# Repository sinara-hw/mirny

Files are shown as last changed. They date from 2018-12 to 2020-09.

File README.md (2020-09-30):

# Mirny

Mirny is a low-cost wide-band PLL/VCO-based microwave frequency synthesiser.

## Design Files

Design files (schematics, PCB layouts, BOMs) can be found at [mirny/Releases](https://github.com/sinara-hw/mirny/releases).

## Wiki

More information can be found on the [wiki](https://github.com/sinara-hw/mirny/wiki).

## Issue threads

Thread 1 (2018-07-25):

Mirny schematics review

CannaCardo, 2018-07-25:
I sketched initial version of schematics ([link](https://github.com/sinara-hw/mirny/blob/master/PCB/Mirny.PDF)).
I've chosen [ADF4351](http://www.analog.com/media/en/technical-documentation/data-sheets/ADF4351.pdf)  ([HMC833](http://www.analog.com/media/en/technical-documentation/data-sheets/hmc833.pdf) has higher price and twice the power consumtion).
I left EEM connectors since I'm not sure which alternative (PoE/ I2C from Kasli and 12V from somewhere/ something else) would be better.
Also I've left out frequency multipliers for now. I understand that this section should be realized as separate microwave PCB and it can be designed separately. I couldn't find any off-the-shelf 40MHz-4GHz multipliers, so that would mean designing it from the beginning or perhaps using a lower bandwidth doubler/tripler?
I appreciate any suggestions and having my mistakes corrected.

gkasprow, 2018-07-25:
Do we really need CPLD here? In case of Urukul it simplified a lot, but here we have only simple SPI. LVC138 should do the job.
Common reference is also good idea. I'm pretty sure that passive divider would do the job. Check what is required power level at the REFin.
Do we need external sync input? We could simply copy clock distribution from Urukul.
If we apply divider at the VCO output, we will end up with plenty of harmonics since the output is just a square wave. Maybe we should let the user to apply the lowpass filter. It can be attached to the SMA directly. Mini-circuits offers broad selection of them.
@jordens going above a few GHz means that we have to use Rogers material which is quite expensive. We can mitigate it by using castellated RF modules dedicated to certain band. I'm a bit sceptical about  amplifier/attenuator working in 35MHz-13GHz range.

gkasprow, 2018-07-25:
Edit. It's not that bad with wideband attenuators and amplifiers.
Let's have a look at:  [HMC424ALH5](http://www.analog.com/media/en/technical-documentation/data-sheets/HMC424ALH5.pdf),  [ADRF5720](http://www.analog.com/media/en/technical-documentation/data-sheets/adrf5720.pdf), there are also plenty of amplifiers that work from almost DC to >20GHz, both from ADI and MiniCircuits. The most problematic components are baluns, but we can use asymmetrical output from the VCO chip. The VCO chip has also programmable output power but from only -4 to 5dBm, I'm not sure if this is sufficient.

gkasprow, 2018-07-25:
I think that EEM is the most capable solution since it gives the user a choice. Once the  Humpback is finished it would give the user freedom in interface selection - USB, Ethernet or DIO.

jordens, 2018-07-26:
@gkasprow
* I'd also prefer to get by without the CPLD. But there are the 4 RF switches, the attenuators, the clock mux, the output status flag from the synthesizers, the LEDs.
* We don't need the sync circuitry. Just clock.
* Right. The harmonics filters shouldn't be fixed or populated by default.
* I wouldn't bother with the ranges above 6 GHz on the basic Mirny either. Leave footprints for MMCX connectors to expose that to custom boards. Maybe we can make Miny smaller in length or width so that those boards can be next to Mirny and don't need to be mezzanines. Consequently I wouldn't bother with the ultra wideband amplifiers and attenuators. Doesn't proper matching get extremely hard if you want to do that from 30 MHz all the way up to 20 GHz?
* I'll also vote for EEM connectivity.

gkasprow, 2018-07-26:
- CPLD seem to be simpler than bunch of serial registers and gives greater flexibility. Let's leave it then.
- sure, we don't need sync.
- what about addding MMCX just about the VCO chip for one who wants to play with their own AFE. We can use VCO's second output for this purpose.
- let's expose some CPLD pins and supply for control of such AFE board. The board could sit on top of Mirny and expose its connectors via the front panel. Maybe 4HP would be enough.
- on board we install just amp, attenuator and switch for let's say 6GHz where FR4 still does the job. But the VCO can work much higher.
- you are right, playing above a few GHz is quite challenging but there are great tools to do so. Have a look at https://www.xmicrowave.com/products/

hartytp, 2018-07-30:
> I think we should survey the users and use cases to decide about:

The use-cases I can imagine for this in our group are.
1. Driving microwave EOMs up to 3.2GHz (calcium hyperfine splitting). This requires a tuneable, but not frequency agile, microwave source with amplitude control and (real-time) switching.
2. Providing a fixed-frequency LO for upconversion. Similar requirements to above

So, my answers to @jordens questions would be:
  - Since we'd want some way of controlling the RF switches from Kasli in real time, EEM seems the right solution for us, but LVDS-over-RJ45 + external power (PoE?) could also work. We could live with ethernet only, and add an external switch, but that's less convenient. I hate USB for lab stuff
  - My preference for the reference would be 125MHz from Kasli via an internal MMCX cable like Urukul. We could probably get away with an XO, but it's nice to have it referenced to our atomic reference so that one doesn't need to check the frequency ever. Since we will generally use this in a rack with Kasli, it seems silly not to use the reference outputs that Kasli provides
  - Power: either EEM or PoE, depending on what we decide above seems easiest
  - We don't need much in the way of fancy features

jordens, 2018-08-01:
* Let's do EEM (will need to be dual slot again for high resolution RF switch signals) and push the rest (Ethernet, PoE, etc down to Humpback/Kasli)
* You'll be checking the frequency anyway due to the finite resolution of the PLL, even with a perfect reference the output won't be what you request in many cases.
* I'd like to leave the XO on board for Humpback use cases or where the MMCX cabling is unnecessary and annoying. And I'd like to make the XO the default. I think it would be best if on one input of the mux there is the SMA and the MMCX in parallel with a capacitor population choice (or even just hve them in parallel, the stub is probably small enough to not matter). And on the other input the XO. That covers all use cases that were mentioned.
* Maybe we can find a less power hungry and cheaper fanout (we don't need the 8 outputs or the divider features).
* Yes. Expose the high frequency (multiplied) output of the VCO on MMCX (DNP FWIW) for custom AFE purposes. Keep the base board good to 4 or 6 GHz.

hartytp, 2018-08-01:
> Let's do EEM (will need to be dual slot again for high resolution RF switch signals) and push the rest (Ethernet, PoE, etc down to Humpback/Kasli)

:+1:

I could definitely live without the high resolution switching/second EEM for this design. But, given that we have the CPLD, if we're going to have one EEM connector, the overhead in adding a second is so low that there doesn't seem any point not having it.

hartytp, 2018-08-01:
> We might want to put a bit more power into the preamplifiers (20dBm output instead of 10dBm) since Mirny is not ad hungry as Urukul.
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
jordens, 2019-01-03:
* Check the output bias inductors. https://freenode.irclog.whitequark.org/m-labs/2019-01-03#1546514242-1546514169; Optimize for wideband match.

hartytp, 2019-01-12:
Why did you decide to go for the adf4355 in the end rather than the adf4356?

hartytp, 2019-01-13:
@CannaCardo some relatively minor comments:
- [ ] it's convention to have traces to ground going down. e.g. having looked at a lot of schematics, I find it mildly jarring that the output capacitors around IC16 go upwards from the trace (same for the LED)
- [ ] in the power budget, can you add a column heading to make it clear which numbers are mA and which are mW etc
- [ ] before going to manufacture we need to finish debugging the power supply issues on urukul related to the LT1763
- is it really necessary to have 4 separate mezzanines rather than just having a single 4-channel mezzanine? IME having lots of narrow mezzanines is mechanically worse and makes layouts nasty on the mezzanines (lots of dead space around boards, can't share common components between boards). What do you think about our idea for stabilizer of having the mezzanine have its own FP and using pin header for the board-board connections (as well as the SMPs)?
- why are there NC pins on the mezzanine connector? Better to ground them?
- [ ] can we reserve some pins on the FPGA for HW rev?
- [ ] PN for TR1? What frequency range does it cover?
- [ ] worth picking a filter that goes up to the 6.8GHz fundamental VCO range? (or at least to the max BW for other components like switches etc)
- [ ] looking at the eval board schematic for the ADF5356, I can see a few differences. e.g. capacitance vales (places where they've used, say, a 10uF and you've used 0.1uF for decoupling). Also, some power pins they've run from separate LDOs, where you've run them from the same LDO. Please double check the eval schematic and make sure that all differences are for a good reason

sbourdeauducq, 2019-01-13:
Probably too late for this design, but in the future let's try to use Lattice FPGAs instead of Xilinx CPLDs (AFAICT they would do the job there), so we can get rid of ISE/Vivado.

jordens, 2019-01-15:
Stick with the CPLD.
IME the free tools for this job are not ready yet. There are still lots of problems and they don't make me nearly as productive as ISE for CPLDs. Also from what I have seen, at least for this application, the CPLD is faster and has more reproducible delays than the ice40.
Vivado won't go. We will be needing Vivado for the foreseeable future.
I'd rather spend my time fixing design flaws and improving the project than trying to get rid of something that we definitely won't get rid anytime soon.

hartytp, 2019-01-15:
One other question: do we really want to bother with all the complexity/mechanical issues around RF mezzanines for this project? Can we get away with something like using solder jumpers to swap between two paths: RFA + AFE; and RFB directly at the output?

If we do need AFE mezzanines, another option that might be simpler/better would be to use a similar form-factor to Stabilizer AFEs (separate EEM FP, pin-header for board-board connectors) and use short coax leads to internally route the microwave output from Mirny to the AFE. This could be simpler and more robust than trying to make the stackup work with SMP bullets.

jordens, 2019-01-15:
I agree. That's what I argued for in https://github.com/sinara-hw/mirny/issues/1#issuecomment-445353727 And a single or at most two mezzanines is fine IMO.
But I would not try to capacitor-route RFoutB to the front panel. Just MCX/MMCX and a pigtail to the panel would probably be electrically better and simpler. For the AFE I also don't like squeezing it into the 4HP space and I don't like the constraint mechanics and interference due to panel/rf/digital connectors.

hartytp, 2019-01-15:
Thakns @jordens. So in order of preference it would be (a) scrap the AFE and use a coax pig-tail (connectors chosen to choose the frequency range) to route RFB somewhere accessible (b) if we have to keep the AFEs then let's limit it to just 1 AFE.

For the pig-tail approach, I assume you'd route them to an adjacent 4HP FP that, for example, just has 4 feedthrough SMAs mounted?

CannaCardo, 2019-01-15:
> can we reserve some pins on the FPGA for HW rev?

I've added 2, should be more than enough.

> PN for TR1? What frequency range does it cover?

TCM2-43X+,  it covers 10MHz-4GHz. Added PN on schematic.

> worth picking a filter that goes up to the 6.8GHz fundamental VCO range? (or at least to the max BW for other components like switches etc)

LFCN-3800+/ LFCN-4400+ would cover BW of front end components (everything works up to 4GHz).

>
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

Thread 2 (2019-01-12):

power supply bug

gkasprow, 2019-01-12:
@jordens discovered [issue](https://github.com/sinara-hw/Urukul/issues/20) with the power supply in Urukul
The DC/DC converter has an output voltage higher than the specification says. We should look for another buck converter producing 7.5V
Another issue is bypass capacitor of LDO - with 100nF it oscillates.

gkasprow, 2019-01-28:
@CannaCardo
- [ ] C170, C175 must be 100pF. Replace with the component from libraries, do not edit parameters with value.

CannaCardo, 2019-01-29:
fixed

hartytp, 2020-07-13:
@CannaCardo should we close? Which release is this fixed in?

CannaCardo, 2020-07-14:
It was fixed in v1.0rc4.

gkasprow, 2020-07-16:
@CannaCardo are you currently working on new revision or only are closing old issues?

CannaCardo, 2020-07-16:
Just closing, I'm working on the TDC atm.

Closed 2020-07-14.

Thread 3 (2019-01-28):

a few last minor issues

gkasprow, 2019-01-28:
- [ ] Please do not add DNP as the Mounted parameter because it is not transferred to the production files. Use variant instead and mark it as not mounted.
- [ ] remember to generate the production files with the appropriate variant enabled
- [ ] move JTAG connector above the ARTIQ logo. The existing location will be covered by the CPCIS adapter.
- [ ] add nice copper balancing as I did for the Banker. You will need this [file](https://www.dropbox.com/s/omaalewtysv5mm3/copper_balancing2.PcbDoc?dl=0). This is a simple hack. Lock all objects on Keep out layer. Then copy keep out mesh with polygons from the file I specified. The polygon parameters are critical. Regenerate polygons. Select the keep out layer only. Remove un-locked mesh from your design. In Xpedition, such copper balancing option costs 10k $ :D My hack is for free.

CannaCardo, 2019-01-29:
- All components marked as DNP are also marked as such in variants.
- There's a separate pick & place, bom and schematic file for every variant, gerbers and drill files are the same across all variants
- JTAG connector moved
- I've added balancing pours with a polygon cutout near rf sections, as floating copper there could cause some troubles later.

hartytp, 2020-07-13:
@CannaCardo this issue looks complete. Can we close?

Closed 2020-07-14.

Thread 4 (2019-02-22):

tag v1.0 production

jordens, 2019-02-22:

jordens, 2019-08-28:
@gkasprow @CannaCardo could you tag the v1.0 production commit and add the correct PDFs/BOM/gerbers?

gkasprow, 2019-08-28:
done

jordens, 2019-08-29:
thanks

Closed 2019-08-28.

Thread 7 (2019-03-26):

Mirny v1.0 tests

gkasprow, 2019-03-26:
The Mirny is ready for tests
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

gkasprow, 2019-03-26:
- [ ] 0R installed instead of  C68 ABCD causing short of 5V power supply rail. 3V3 rail depends on this voltage. After removing shorts, all supples are fine.

gkasprow, 2019-03-26:
CPLD is detected over JTAG

gkasprow, 2019-03-26:
@CannaCardo it's time to connect ADI devkit and check if the synthesizers are working

CannaCardo, 2019-03-26:
Ack, I should be in Warsaw on Thursday to test it.

jordens, 2019-03-26:
Nice!

gkasprow, 2019-04-04:
the CPLD cannot really set Hi-Z on CLK_SEL signal. the state is close to VCC.
With a touch of the probe, the Hi-Z appears and stays until power down. So it looks like additional init sequence would be needed that first sets low state and then Hi-Z.

gkasprow, 2019-04-04:
Other than that Mirny works with ADI devkit as a controller.

gkasprow, 2019-04-04:
We have some issue with 26kHz and its second and third harmonics. The carrier is 100MHz. Moreover, the analyzer sees the carrier shifted by 1kHz.
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

gkasprow, 2019-04-04:
It looks like the noise source was outside. With analyzer and supply connected to same mains outlet the spectrum looks much better now.
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

jordens, 2019-04-04:
It works on urukul. Just tristate it.

jordens, 2019-04-04:
What are the conditions and settings there? With div32 and a 3.4 GHz vco the datasheet gets to -131dbc/hz at 10khz and 64 mhz pfd.

gkasprow, 2019-04-04:
the SSA I have is not a really good one. It is a software option to the spectrum analyzer. It's good for quick debugging, not real measurements.
With CMC added to the 12V power entry, the 26kHz peak disappeared.
We will make measurements with real SSA in a few days.

gkasprow, 2019-09-18:
[Here](https://www.dropbox.com/s/8773l9b8eklw5bs/praca%20mgr%20277384_inz.pdf?dl=0) is the thesis of Krzysztof Belewicz

jordens, 2019-09-18:
Well done. Congrats @CannaCardo

jbqubit, 2019-09-18:
Thanks for the detailed writeup @CannaCardo! Great work!

Closed 2020-09-30.

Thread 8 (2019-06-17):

replace Si53312-B-GM by Si53340-B-GM

jordens, 2019-06-17:
* No need for 6 unused outputs
* No need for input divider
* No need for power-hungry LVPECL
* Removes one BOM line

gkasprow, 2020-09-30:
done
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

Closed 2020-09-30.

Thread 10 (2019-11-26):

[RFC] Phase lock application

hartytp, 2019-11-26:
We have an application where we'd like to generate two tones at 1.6GHz. One needs to be locked to a fixed external reference, the other needs to be phase locked.

It seems like Mirny might offer a nice way of doing this if we did something like:
- Add a footprint for a low phase noise VCXO which can be populated instead of the XO (or, better, aim for a pin-compatible part)
- Hook the tuning pin to an MMCX/whatever. Maybe add an RC filter or even a diff-amp to give noise rejection. All of this would be DNP by default
- have some means of getting some channels clocked from the VXCO and some from the external reference. This could be as simple as adding a DNP'd MMCX connector for each channel and solder jumpers that can be used to inject an external clock (that's somewhat useful for debugging anyway).

Thoughts?

jordens, 2019-11-26:
To clarify: you want one voltage controlled Mirny channel and one controlled via a reference frequency?
Adding the tuning option to the XO is good.
And solder jumpers to select between DNP MMCX per channel and the clock fanout is also fine. But simpler yet and without any new connectors, you can use jumpers to choose between IC17:Q1-Q3 (VCXO or MMCX) and IC13:Q1-Q3 (#8, FP SMA or VCXO/MMCX) for three of the four channels. That way you can run 0 to 3 channels from the VCXO (or MMCX) and 4 to 1 channels from the SMA input.

hartytp, 2019-11-26:
> To clarify: you want one voltage controlled Mirny channel and one controlled via a reference frequency?

Yes. Basically, one as a reference for the mixer LO and one that we can lock.

We'll probably end up using Stabilizer for the lock so this could potentially be a Stabilizer mezzanine but the work to reward effort feels better by reporuposing Mirny.

> But simpler yet and without any new connectors, you can use jumpers to choose between IC17:Q1-Q3 (VCXO or MMCX) and IC13:Q1-Q3 (#8, FP SMA or VCXO/MMCX) for three of the four channels. That way you can run 0 to 3 channels from the VCXO (or MMCX) and 4 to 1 channels from the SMA input.

Yep, that's another route I thought of which I'd also be happy with.

hartytp, 2019-11-29:
Having said all that, this would be pretty trivial to do as a Stabilizer AFE card. 1 Crystal, 2 PLLs and some regulators and that's it AFAICT. Basically just a copy-paste from a few other designs so <1 day of work I'd guess.

gkasprow, 2019-11-29:
You can also connect Mirny to the stabilizer via EEM.

dhslichter, 2019-12-02:
Why not use Mirny as a carrier generator at ~1.25 GHz, split the output, and then use two separate mixers with two Urukul channels to mix up to 1.6 GHz?  The carrier and other sideband can be stripped easily with high-pass filters/notches, then all frequency and phase tuning between channels can be done digitally with the Urukuls.  If the Mirny can be locked to an external reference already, you're set.  You could make a little eurocard with splitter, mixers, filters, some SMA connectors on the front panel, even some ERA-4 or equivalent amps to boost the output power a bit if desired (without amps it could be a completely passive board, with amps you would have to provide a power supply from in the crate).

hartytp, 2019-12-02:
> Why not use Mirny as a carrier generator at ~1.25 GHz, split the output, and then use two separate mixers with two Urukul channels to mix up to 1.6 GHz?

(a) because there is a doubling cavity involved so we'd need 1.6GHz and a 3.2GHz tones (b) because it feels more expensive/complicated than hooking a stabilizer up to Mirny. What would do the digital modulation of Urukul? Kasli? I'd like this to be a standalone unit with good ethernet diagnostics (e.g. streaming noise traces). That feels easier to do with Stabilizer than Kasli.

I think the Vco tune input is a good thing to have for Mirny. But, currently I'm leaning towards doing this as a high-frequency version of Pounder with the DDSs replaced by ADF PLLs.

hartytp, 2019-12-31:
closing in favour of https://github.com/sinara-hw/Homodyner/issues/1 and https://github.com/sinara-hw/mirny/issues/11

Closed 2019-12-31.

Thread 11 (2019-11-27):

VCXO

hartytp, 2019-11-27:
The current XO is a crystek [CCHD-950](https://www.crystek.com/crystal/spec-sheets/clock/CCHD-950.pdf) costing ~£20 in singles

The a footprint-compatible VCXO part is [CVHD-950](https://www.crystek.com/crystal/spec-sheets/vcxo/CVHD-950.pdf). This is about the same cost (actually, very slightly cheaper) and has decent [availability](https://octopart.com/search?q=cvhd-950-100.000).

I'm happy to keep the XO as the default population option, but can we have either a variant with the VCXO or just an annotation mentioning that this is a suitable alternative part?

I'd like to break the tuning pin out to an MMCX. Probably via a difference amplifier (to remove ground small levels of common-mode noise), offset addition and attenuation to match +-10V to the VCXO's range. Then probably an RC filter to kill any high-frequency noise. I'll sketch out a suggestion for this design at some point when I have time.

hartytp, 2019-11-27:
@cjbe FYI this is the VCO noise spec https://octopart.com/search?q=cvhd-950-100.000

jordens, 2019-11-27:
I think we already went for the tunable part in Urukul and mid-pointed tuning input.

hartytp, 2019-11-27:
For reference, the PLL noise model is:
- assume f_ref=125MHz, N = 13 (f_out=1.625GHz)
- in-band phase noise floor is `-227dBc/Hz +10log10(125e6) + 20log10(13)=-124dBc/Hz`
- FWIW, that's equivalent to reference noise of -146dBc/Hz
- 1/f noise is `-121dBc/Hz + 10log10(10kHz/f_offset) + 20log10(f_rf/1GHz)` so the 1/f phase noise at 10kHz offset is `-117dBc/Hz`

VCO noise is

![Uploading image.png…]()

hartytp, 2019-11-27:
If that's actually an issue and we ever made a mezzanine, we could consider using e.g. an HMC830 which has ~10dB lower noise, but I don't really think it's a problem. tl;dr it looks like this will work nicely!

hartytp, 2019-11-29:
FWIW, the HMC830 specs are

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

So 3dB better for the in-band noise floor (although, note that the PFD can only hit 125MHz for integer-N mode)

I believe the flicker noise floor is normalized to 1Hz offset, so equivalent to 228 at 10kHz. i.e. approx 7dB better than the ADF PLL. So, not a huge difference between the two TBH.

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

The ADF VCO noise actually looks a little better.

So tl;dr either part is probably fine.

gkasprow, 2020-09-30:
I copied the schematic from Urukul
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

Closed 2020-09-30.

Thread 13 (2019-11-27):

transformer part numbers missing from schematic

hartytp, 2019-11-27:
Also, let's make sure these are done consistently with other designs like phaser.
- where possible/appropriate use same transformer part numbers as other designs
- for external clock inputs try to do the layout such that we can use the transformer to provide galvanic isolation (not an option for microwave inputs)

gkasprow, 2020-09-30:
what about the same transformers as in Phaser design?
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

hartytp, 2020-09-30:
fine by me

hartytp, 2020-09-30:
@gkasprow shouldn't the input ground be tied to the SMA ground, and only connected to the PCB ground through the 0R resistor though? That way we can use the transformers to provide galvanic isolation if desired (but let's not make that the default population option). IIRC that's what we're now typically doing elsewhere...

gkasprow, 2020-09-30:
ah, yes, good point.

Closed 2020-09-30.

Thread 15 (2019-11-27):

PGOOD too high

hartytp, 2019-11-27:
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

In practice it may not matter as the pull up is weak, but ideally we should avoid clipping on the ESD diodes

hartytp, 2019-11-27:
1.5V/5.6K is 300uA so within spec, so maybe not worth changing the design?

hartytp, 2019-11-27:
I guess this is consistent with the latest Urukul, so we decided it's not actually an issue

hartytp, 2019-11-27:
Worst-case current is 7.5V/5.6K = 1.33mA so a bit on the high side but still within the abs max ratings.

Closed 2019-11-27.

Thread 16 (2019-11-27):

TPS62175DQC

hartytp, 2019-11-27:
Why arent' we using the same PN as Urukul out of curiosity? Makes the design review easier if I'm just looking for diffs between the two designs...

gkasprow, 2020-09-30:
it is already used in DIO boards. We can switch to the same one as in Urukul.
In Urukul it was used to generate 7V5 which was out of it spec that's why was replaced by TPS62148.
Here we generate 5V5 which is fine.

hartytp, 2020-09-30:
@gkasprow I don't feel strongly about this (beyond a general preference for reusing components from other design where possible) so do what you think is best.

gkasprow, 2020-09-30:
Let's go for Urukul one. It has higher current, mezzanines may need it.

Closed 2020-09-30.

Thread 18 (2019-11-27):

Different supply for digital rails?

hartytp, 2019-11-27:
Shouldn't the noisy PLL digital rails be run from a separate supply to the analog rails? E.g. run them directly from their own SMPSs.

hartytp, 2019-11-27:
Maybe not needed if the digital interface is only used during configuration?

gkasprow, 2020-09-30:
I'm a bit afraid of connecting it to the "digital" P3V3. I can replace the FB with an inductor that makes a low frequency filter.

gkasprow, 2020-09-30:
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

hartytp, 2020-09-30:
sure, whatever you think is best here...

Closed 2020-09-30.

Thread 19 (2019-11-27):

Analog supply decoupling

hartytp, 2019-11-27:
Should there be FBs to isolate the various anlaog supplies that are derived from the same LDO?

hartytp, 2019-11-27:
Well, we're actually not far off the [eval board design](https://www.analog.com/media/en/technical-documentation/user-guides/EV-ADF5356SD1Z-UG-1087.pdf).

The only real difference I see is that the eval board uses separate LDOs for the output stages. I assume this isn't really worth doing and the FBs will be fine...

Other than that I didn't spot any issues during a quick design review. Nice job all who worked on this one!

gkasprow, 2020-09-30:
can we close it?

hartytp, 2020-09-30:
@gkasprow so long as you're happy with the current design (e.g. not using separate LDOs as the eval board does) you can close this issue. I'll leave the final call to you.

Closed 2020-09-30.

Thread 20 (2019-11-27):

RFoutB-

hartytp, 2019-11-27:
why isn't this labelled AGNDrf2 and tied directly to GND1 as in the eval board?

jordens, 2019-11-28:
I think this depends on the chip. The non-doubling are differential. Otherwise this is the Rf b return.

hartytp, 2019-11-28:
That's what I assumed. AFAICT for the chip on Mirny right now this should be grounded as in the eval board. Maybe add shunt resistor to ground in parallel and DNP the cap?

jordens, 2019-11-28:
I'd just test whether this works fine with the doubling variants and if not check whether making the R 0 is sufficient to enable AC return. If it works fine as now then no changes are needed.

gkasprow, 2020-09-30:
I added 0R for ADF5356/5355 versions.

Closed 2020-09-30.

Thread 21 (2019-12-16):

[RFC] OPLL AFE

airwoodix, 2019-12-16:
We are considering using Mirny to generate the ca. 7 GHz MW we use to mix down rubidium Raman phase lock beatnotes (ca. 6.8 GHz). Besides the necessary range extension (using RFoutB), it would be great to integrate most of the chain as a Mirny addon-board.

The full chain would be something like (x4):

```
PD input -- gain +16dB  -- DBM -- LPF (200 M) -- [PFD -- CP] -- LPF -- output
                            |
                     7 GHz from RFoutB
 ```

For the PFD/CP, something cheap and simple like ADF4154 or even ADF4110 would be great. The reference for the the PFD would come from an external Urukul channel. Since there're four lines free on the Mirny EEM, these can be routed to the AFE and control the PLL chip.

RFoutB probably needs preconditioning to saturate the mixer.

A simpler version of the board would drop the PLL if that's too complicated / not generic enough. In any case, a down-converted beatnote monitor is a useful feature.

What are your thoughts?

jordens, 2019-12-16:
A heterodyne design might be best. You would be able to reuse Pounder. 1st IF at ~100 MHz.

```
Mirny - gain - DBM LO
PD - gain - DBM RF - LPF - Pounder (gain, DDS LO, DBM, LPF, gain) - Stabilizer
```

hartytp, 2019-12-16:
@airwoodix Hi! BTW this is well-aligned with something we're thinking about.

We had a couple of thoughts about ways of doing this. e.g. https://github.com/sinara-hw/mirny/issues/10

As @jordens points out there are many ways of skinning a cat, but reusing Pounder seems like a good idea.

Currently, the option I'm leaning towards for our application would be to create a high-frequency (1-4GHz at least) version of Pounder. The idea is
- have the entire RF chain (filters, mixer, amps, variable attenuator etc) on a Stabilizer mezzanine.
- replace the twin DDS on pounder with a pair of PLLs.
- one PLL uses an external reference
- the other uses a ~100MHz VCXO that's steered by the DAC on pounder to provide the phase lock

This provides a really nice integrated solution to the problem that can span a wide frequency range (can also have RF and LO at different frequencies if e.g. modulation is done before optical doubling). We can largely reuse the pounder design so the HW changes are relatively minimal.

jordens, 2019-12-16:
The other thing that I would consider in general for these phase measurements is going superhet and having some ~200 kHz IF (instead of DC) on Pounder and doing the rest in digital domain in Stabilizer. That's a free rejection of all the low frequency noise and instability near DC. Just needs proper clocking of Stabilizer.

hartytp, 2019-12-16:
@airwoodix what PFD/CP are you thinking of? Are you intending to lock the ADF to the beat note directly? Might be better to lock the ADF to a VCXO with a high bandwidth and then lock the VCXO to stabilize the beat note. The VCXO has much lower noise/better stability than the ADF VCO so you can use a narrower bandwidth lock, can do S/H etc

hartytp, 2019-12-16:
That's what we would do on our high-frequency Pounder version...

airwoodix, 2019-12-16:
Thanks for the feedback. Great ideas, I was looking at something much simpler (and cheaper).

From a pure accounting point of view, I'd priviledge a Mirny mezzanine since this is one board less (we need RFoutB gain anyway so the Mirny board is unavoidable).

@hartytp I was looking at ADF4154 as PFD/CP with no extra VCO but it sounds indeed convincing to add an extra VCXO. The main argument was to keep the system as simple as possible and the availability of lines on the EEM Mirny is attractive to me.

The phase lock's frequency offset needs to be dynamically controlled. The easiest would be over EEM, otherwise we'd need a lot of extra fw development for Stabilizer. Hooking up a Urukul channel or multiplexing a DDS next to the PLL chip on the Mirny addon board is easy and integrates seamlessly into the system (saving the indirection through Stabilizer).

@jordens of course, a superheterodyne approach is better but also more complex.

hartytp, 2019-12-16:
> Thanks for the feedback. Great ideas, I was looking at something much simpler (and cheaper).
From a pure accounting point of view, I'd priviledge a Mirny mezzanine since this is one board less (we need RFoutB gain anyway so the Mirny board is unavoidable).

FWIW my proposal is also only 1 board (stabilizer) + 1 AFE card so I don't think it will be more expensive than Mirny + AFE in terms of hardware production costs.

What are you planning to use to do the feedback controller? Will you do this in analog (boo!) or have a digital controller. I'd suggest you consider the latter. Not just because it's so much nicer to tune loop filters digitally (particularly if you might at some point want e.g. a double integrator to kill acoustic noise without having to have a really wide lock bandwidth etc), but because of the diagnostics. e.g. we've found it so useful to be able to stream error signals for diagnostics (see if a lock is ringing) do digital relock etc.

From that point of view using Stabilizer is the obvious choice for the lock (whether you use Stabilizer to drive the VCXO on Mirny or put the PLL on a Stabilizer AFE).

> @hartytp I was looking at ADF4154 as PFD/CP with no extra VCO but it sounds indeed convincing to add an extra VCXO.

I can't remember (don't have schematics in front of me) if Mirny even exposes the Vtune input right now to allow an external lock signal. So, locking like that might require hardware modifications.

> The main argument was to keep the system as simple as possible and the availability of lines on the EEM Mirny is attractive to me.

Stabilizer is an EEM too :)

Anyway, I take all your points. As I said, there are many ways of skinning a cat. I have my own ideas about how I'd do this but I'll be really interested to see what system you settle on. If you do a nice job of it then it would be a really welcome addition to the Sinara ecosystem.

airwoodix, 2019-12-16:
> FWIW my proposal is also only 1 board (stabilizer) + 1 AFE card so I don't think it will be more expensive than Mirny + AFE in terms of hardware production costs.
Given the frequency range, we need to use the ADF5356's second output (``RFoutB``). Would you expose it directly on the front panel from the SMP connectors? I'd take the opportunity to at least at gain (possibly with digital step attenuators driven by a SR like the PGIAs on Sampler).

We'd mostly use Stabilizers for the feedback (I totally support your points), but also likely Toptica DLC for the diode lasers (because we anyway use them for the current/PZT drivers). Hence the idea to put most of it on Mirny... Other experiments in the group might also be more convinced if they only need a Humpback and a Mirny + AFE (ok, with a lot of software, this is also valid for Stabilizer (as EEM upstream) + AFE + Mirny).

> I can't remember (don't have schematics in front of me) if Mirny even exposes the Vtune input right now to allow an external lock signal. So, locking like that might require hardware modifications.

It doesn't. Either we misunderstood ourselves or I'm stupid but I don't see the need to feedback on Mirny. I had an optical PLL "à la" Vescent D2-135 in mind so we'd feed back on the laser directly. Or is there something wrong with this approach?

>> The main argument was to keep the system as simple as possible and the availability of lines on the EEM Mirny is attractive to me.

> Stabilizer is an EEM too :)

Sorry should have written "on Mirny's EEM". With @jordens Mirny CPLD gateware, EEM4-7 are free to use on the mezzanine.

I'll work out the options tomorrow and come back with more questions :) Overall, I'd mostly be happy minimizing the amount of firmware/gateware to write. And honestly, as far as I'm concerned, it's easier to write glue gateware for the Mirny CPLD and a simple coredevice driver than extending the Stabilizer firmware.

hartytp, 2019-12-16:
> I had an optical PLL "à la" Vescent D2-135 in mind so we'd feed back on the laser directly. Or is there something wrong with this approach?

Aah, okay, makes sense.

I assumed you were using one output of Mirny to drive a modulator and wanted to do the optical phase lock by feeding back to the RF.

gkasprow, 2019-12-30:
Can we move it to the [new repo](https://github.com/sinara-hw/Pounder_HF) ?

hartytp, 2019-12-30:
@airwoodix can you sketch out a full block diagram of the system you want to build please?

 I have in mind a stabiliser homodyne afe based on pounder. Idea is to use one pll to provide a mixer ref. Lock is achieved either (eg population options) by using an external modulator which is driven by a second pll who’s ref is provided by a vcxo driven by stabiliser or using the stabiliser output to drive some other actuator (eg laser PST).

If there is enough overlap it would be good to design an afe that can cover both cases.

airwoodix, 2020-01-02:
I'd lean towards separating the frequency ranges (6G+ vs 3G-) and build two daughter boards: one for Mirny that deals with applications that require RFoutB and one like Pounder/Homodyner for the work in the 3G- domain.

For the 6G+ range, what about a Mirny AFE with chains like this:

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

The application is our typical phase lock for the Rb interferometry systems. The RF input is a beatnote at ca. 6.8 GHz. RFoutB covers the range 6.8 GHz - 13.6 GHz. Components suggestions try to cover at least up to the (neutral) Cs hyperfine frequency at 9.2 GHz.

RFoutB delivers 0-2 dBm, with -20 dBm fundamental VCO feedthough. The HPF doesn't cost much and probably makes this better. The mixer needs 17 dBm LO drive. All amplifiers have the same footprint. Would be great to keep the output LPF in a MCL FV1206 package to have more flexibility (and stay compatible with Urukul).

To achieve phase/frequency offset lock, the RF signal can be fed to Pounder as @jordens suggested. I think that my initial suggestion to put the phase detector on the Mirny AFE is not flexible enough although the full solution will require a significant amount of firmware development for Stabilizer.
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
hartytp, 2020-01-02:
> It's an option, but less convenient -- I'd rather just have Stabilizer and a single AFE than: Stabilizer+Pounder+Mirny+AFE as well as the wiring between them and something to drive Mirny (Kasli? Humpback? Stabilizer EEM connector and write Stabilizer firmware to control Mirny?).

A bit of extra context: we're looking for a fixed frequency offset lock between a pair of lasers. So, it's useful to have something that can easily run standalone (rather than plugging into one of our ARTIQ Kaslis). Hence a PoE module like Stabilizer is ideal for this (although you could still connect it to a Kasli, albeit with limited timing resolution, using the Stabilizer EEM).

gkasprow, 2020-09-30:
@hartytp what are your needs here? Shall we proceed? The Almazny is nearly done and we can take care of this design.

gkasprow, 2020-09-30:
@airwoodix

hartytp, 2020-09-30:
@gkasprow for our specific application, the best method would still probably be a specific Stabilizer mezzanine. As described above, this would be something like:
- Two PLL ICs
- One clocked from an external reference, used to feed mixer LO
- the other clocked from a VCXO that is tuned by the stabilizer DAC to lock
- RF input/mixer/signal conditioning largely copied from Pounder, but changing the bandwidth of some components to work to a few GHz

The current Mirny design gives us a way of building something like the above using a stabilizer + mirny + containerized mini circuits bits. Modulo concerns about the cross-talk from the clock jumpers and CMRR of the VCXO input, I think this does everything we could want without building a dedicated card (which may be more effort than it's worth).

airwoodix, 2020-09-30:
@gkasprow are the schematics of the Almazny already online?

gkasprow, 2020-09-30:
@shanasz has issues with github, they should arrive today.

Closed 2020-09-30.

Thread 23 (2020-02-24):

More flexible clock routing

hartytp, 2020-02-24:
https://github.com/sinara-hw/mirny/issues/10#issuecomment-558618102

gkasprow, 2020-09-30:
@hartytp @jordens would such wiring work for you?
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

hartytp, 2020-09-30:
That arrangement allows one to select between the SMA and the VCXO/MMCX on a per-channel basis. For our use-cases, it would be more convenient to select between the MMCX and the SMA/VCXO on a per-channel basis, but the above is acceptable. @jordens preferences here?

@gkasprow based on our previous experience, I guess we expect quite a bit of cross-talk from the DNPd jumpers, do we?

gkasprow, 2020-09-30:
we can use T-type jumpers, when unused, the central part is grounded.

jordens, 2020-09-30:
Either is fine by me.

jordens, 2020-09-30:
Default population being all channels clocked from IC13.

gkasprow, 2020-09-30:
I added such a scheme. To avoid dangling nets, the segment is terminated on both sides. To improve isolation, unused net segments can be grounded. That should solve the issue with crosstalk.
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

gkasprow, 2020-09-30:
I also changed the assignment - now we select between MMCX and the SMA/VCXO.

gkasprow, 2020-09-30:
The layout/routing of the clocking section
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

Closed 2020-09-30.

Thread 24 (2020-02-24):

VCO tune CMRR

hartytp, 2020-02-24:
https://github.com/sinara-hw/Urukul/issues/37#issuecomment-588092910

To do: try driving the VCO from a stabilizer and measure the DDS output noise spectrum. If it's bad, look at putting in a proper InAmp solution with much better CMRR (and maybe a CM/DM EMI filter).

gkasprow, 2020-09-30:
I took the Urukul [issue](https://github.com/sinara-hw/Urukul/issues/37) into account
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

hartytp, 2020-09-30:
This would be clearer with the population options shown, but I think I understand what's going on...I'd feel more confident with this if we'd tested on Urukul, but the approach seems sensible (assuming we can get away without a true differential front end to suppress ground noise)

hartytp, 2020-09-30:
@gkasprow what limits the tuning bandwidth here? Is it C100? I assume we want a filter to stop RF pickup etc getting onto the VCO.

gkasprow, 2020-09-30:
default population:
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
the issue is with filtering the + divider - for low frequency if will have more than 5k and its CMRR for low frequency would be worse. I'd prefer to stay with one used in Urukul.

hartytp, 2020-09-30:
don't C100 + R78 give an nice filter?

gkasprow, 2020-09-30:
it does. But in one of the Urukul issues somebody wanted additional RC filter at the opamp positive input. That's why I added R99, R100 and C107

hartytp, 2020-09-30:
Fine. Well, we have a pretty sensible topology and lots of pads to play with here, so it seems like a decent starting point. Would be good for someone to actually play with a phase lock...

Closed 2020-09-30.

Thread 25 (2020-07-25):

High frequency mezzanine

cjbe, 2020-07-25:
How far advanced are the plans for the high frequency mezzanine?

I need some sources around 5-12 GHz for which Mirny+mezzanine would be ideal. For my use case all I would require on the mezzanine is matching and switching. Switchable attenuation would be a nice to have.

Does anyone have any appetite to specify / use / build this? If so I can put some effort into crystallising specifications.

gkasprow, 2020-07-25:
@cjbe So far there was no such request.
If you specify it, we will build it. I have a budget for RF engineers and prototypes.
Just find suitable RF components and write the spec.

gkasprow, 2020-07-25:
U can use a free RF QUCS simulator to do a rough estimation if the components make sense.
This is an example project of ISM transverter I designed and my colleague verified with this tool
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

cjbe, 2020-08-01:
Here is a broad specification:
* max output power: ~5-10 dBm (enough to match well to standard 25-35 dB gain amps)
* frequency range: 4 GHz - 13 GHz (ie the complement of range covered by the main outputs)
* switching with extinction >~ 50 dB

Optional:
* step attenuator with >15 dB range, <1 dB LSB

### Components
All chosen from Analog / HMC

#### RF Switch
The best option looks like [HMC1118](https://www.analog.com/en/products/hmc1118.html) ($7):
Range 0-13 GHz
Typical IL 1.3 dB
Off isolation: 35 dB @ 10 GHz, 50 dB @ 4 GHz
Supplies: +3.3V, -2.5V
All other options are more expensive, give only marginally better extinction, and still require a negative rail

The extinction at 13 GHz is lower than desirable - hitting our target may require using two switches in series.

#### Amplifier
[AVA-183A+](https://www.minicircuits.com/pdfs/AVA-183A+.pdf) ($8):
Range 0.5-18 GHz
gain: 14 dB @ 10 GHz
P1dB: 19 dBm @ 10 GHz
Supply: +5V

#### Attenuator
[HMC424ALP3E](https://www.analog.com/media/en/technical-documentation/data-sheets/hmc424a.pdf) ($15)
Range DC-13 GHz
0-31.5 dB in 0.5 dB steps
6 bit control bus
Supply: -5V
IL: 4 dB @ 10 GHz

Can drive with a 74HC595 shift register, giving an SPI interface that looks very similar to the attenuators in the 0-4 GHz Mirny path.

cjbe, 2020-08-01:
On the v1 Mirny there are only 8 digital IO signals - this is fewer than desirable for a fully capable 4 channel mezzanine.

The RF switches need dedicated IO lines (so total 4x), leaving only 4x lines for the 4 attenuators. To fully and independently connect these requires 5x IO lines each, giving a total of 20 lines. Without loosing any flexibility of use, we could reduce this to 3x lines each (data, clock, latch), requiring a total of 12 lines. This requires an extra 8x IO lines.

It looks like we can find 8 free IO on the CPLD (using 7 NC, and 1 from a TP). The neatest way to do this would just be to use a larger 0.1" header; this would require breaking backwards compatibility, but I assume there are few enough of these boards in the wild that this is not a great concern (thoughts @gkasprow @jordens ?)

gkasprow, 2020-08-12:
Yes, we plan new revision. No problem adding other IOs. I opened dedicated issue.  There were so far only 4 or 5 boards produced.
My coleague (Staszek) started working on this mezzanine project.

gkasprow, 2020-08-12:
@cjbe Any idea for the mezzanine name? I'd like to open dedicated repo.

sotirova, 2020-08-13:
How about Almazny? It sounds somewhat similar to mezzanine and is close to Mirny...
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

jonathanpritchard, 2020-09-02:
We would also be interested in a mezzanine with this specification, also agree two switches would be better to achieve sufficient high frequency isolation

cjbe, 2020-09-02:
@jonathanpritchard great!
@gkasprow what do you need from us to get this moving?

gkasprow, 2020-09-14:
I assume this would be 4-channel design.
I think we have all is needed to start design process.

gkasprow, 2020-09-14:
@shanasz is our microwave expert, he takes care of the RF design.

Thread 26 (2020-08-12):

more IOs

gkasprow, 2020-08-12:
add more IOs (#25 )

gkasprow, 2020-09-30:
I added 8 extra IOs. The connector is longer but fully compatible with v1.0

gkasprow, 2020-09-30:
It is however shorter than EEM one to avoild plugging the cable.

Closed 2020-09-30.

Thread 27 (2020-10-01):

mechanics

gkasprow, 2020-10-01:
- [x] make sure the panel and connector placement is identical as in Urukul v1.5
- [x] make sure the RF connectors are identical as in Urukul v1.5

gkasprow, 2020-10-06:
- [ ] use the same LEDs as in Urukul

jordens, 2020-10-07:
@gkasprow thanks. Lookgs good from my side.

Closed 2020-10-06.

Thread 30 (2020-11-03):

MFG issues

gkasprow, 2020-11-03:
R0402_47K_1%_0.0625W_100PPM has wrong PN field which indicated 51k resistor

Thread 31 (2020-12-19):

Move "INT CLK IN" silk to near connector

cjbe, 2020-12-19:
On v1.1 the "INT CLK IN" silk is in the bottom left of the PCB, whereas the connector is in the top right.

gkasprow, 2021-10-07:
fixed

Closed 2021-10-07.

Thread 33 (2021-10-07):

v1.1.1 changelog

gkasprow, 2021-10-07:
In v1.1.1 only cosmetic changes were introduced:
- SMA connector alignment #32
- J15 connector moved to match Urukul and Phaser #32
- fixed resistor MFG PN #30
- moved silkscreen #31

Closed 2023-12-13.

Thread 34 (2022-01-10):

R46 power

gkasprow, 2022-01-10:
use higher power R46, there is no margin left when IC2 consumes max current
1210 would be fine

gkasprow, 2023-11-03:
replaced with 39R 1210

Closed 2023-11-03.

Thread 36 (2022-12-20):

Output crosstalk due to lacking isolation

nkrackow, 2022-12-20:
The outputs of current Mirnies V1.1 suffer from significant crosstalk:
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

Pushing on the PCB close to the front panel makes the crosstalk vary by more than 10 dB.
The SMA shield is shorted to the front panel at DC.

This implies that there is a problem with the front panel, probably the SMA pins making connection.
The same issue appears on other high frequency sinara modules: https://github.com/sinara-hw/Urukul/issues/68

@gkasprow @akaminska

kaolpr, 2022-12-20:
I believe SMA shield is just shorted to FP in a defined assembly variants:
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

gkasprow, 2022-12-20:
yes, but the impedance of short-circuit may be non-negligible for 1GHz and above

akaminska, 2022-12-21:
We will try to re-create and investigate the problem

gkasprow, 2022-12-21:
To do this, we need more info about the setup. Preferably some photos depict how cables are placed.

jordens, 2022-12-21:
@nkrackow sent a photo to @akaminska AFAIK

gkasprow, 2023-03-22:
we plan new revision. What if we remove the assembly variant and connect the SMA connectors to solid GND?

gkasprow, 2023-11-03:
added direct connection like in Urukul

Closed 2023-11-03.

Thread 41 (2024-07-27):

Phase noise measurements

maria-nowicka, 2024-07-27:
**The phase noise of the microwave synthesizer was measured using the internal oscillator in Mirny, and then compared when the module was clocked by the Kasli controller.

You can find the phase noise measurement for different frequencies in this table:**

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

**For the same configurations as above, the table below shows: peak to peak, mean, and standard deviation.**

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

**The graphs below are an extension of the tables.**
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

**Here is the setup used for the measurements:**
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

gkasprow, 2024-07-28:
It looks like we have at least 3 issues here: DC/DC converter noise on Mirny, DC/DC converter noise on Almazny and Kasli DC/DC converter noise. I can see the first and the third harmonics.

gkasprow, 2024-08-14:
I verified Mirny in the same setup (same controller, same power unit, same cables) but with E5052B SSA and in my home lab (no RF sources nearby)
And it looks completely different.
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

gkasprow, 2024-08-14:
Mirny driven from Kasli
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

gkasprow, 2024-08-14:
I managed to recreate same plots.
One needs to switch units of spurious from Normalised to Power
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

gkasprow, 2024-08-15:
I was playing with LC filters after the 5V5 converter and it looks like the 1.3MHz noise comes through the ground loops.
We have two more DC/DC covnerters but they are within the ADI module and we can't see them in the phase noise spectrum
The 3kHz noise is also caused by the 1.3Mhz converter - it produces ripples of such frequency.
I'll dig deeper into it because we have such supply in many other designs.

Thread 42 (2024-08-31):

new DIOT version

gkasprow, 2024-08-31:
A new DIOT/EEM version is on the way:
- take the existing design and replace CPLD with ICE40 - circuit and EEM connectivity copied from Fastino-DIOT (with proper power sequencing)
- get rid of LVDS translators
- move power supplies away from DDS chips, we have a lot of board area
- make sure all points are checked: https://github.com/sinara-hw/DIOT-Template/issues/1

gkasprow, 2024-11-04:
@micbeldyga

The design looks good. Issues:

- name it Mirny DIOT v 1.6
- add legend to SPI connector and DIP switches
- add DIOT panel (6HP) as DIOT assembly option;
- add SPM connectors legend
- add EEM and DIOT variant, add adf5356-DIOT variant, existing ones keep as EEM variants
- make sure to select IC22 or IC24 in variants

micbeldyga, 2024-11-09:
Done 6ea116b25847b98eab5f359c992dccd5cc83ebca

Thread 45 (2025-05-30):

V1.6 schematic review

martafafara, 2025-05-30:
I've checked the schematic with special attention paid to DIOT part and I have some remarks:

- [ ] MIC5219 output capacitor should be tantalum or aluminium as @gkasprow wrote in the [EFC issue](https://github.com/sinara-hw/EEM_FMC_Carrier/issues/57)
- [ ] I suggest to use "No DRC" mark at any intentionally unconnected net
- [ ] IC40 should have all outputs loaded as in DIOT template. The similar issue occurred in [Silpa_HL](https://github.com/sinara-hw/SiLPA_HL/issues/24#issuecomment-2480730424)
- [ ] In DIOT variant IC43 should be "not fitted"
- [ ] SC18IS602B (IC22) is obsolete so IC24 (its replacement) should be set at fitted, not opposite.
- [ ] FPGA supply filters are not consistent with [Hardware checklist](file:///C:/Users/Marta/Downloads/FPGA-TN-02006-2-3-iCE40-Hardware-Checklist.pdf) - there should be 4.7uF per every bank (instead of 10uF) and 100nF per every pin (check the number of placed capacitors). 100pF is redundant
- [ ] FPGA N14 pin should be unconnected

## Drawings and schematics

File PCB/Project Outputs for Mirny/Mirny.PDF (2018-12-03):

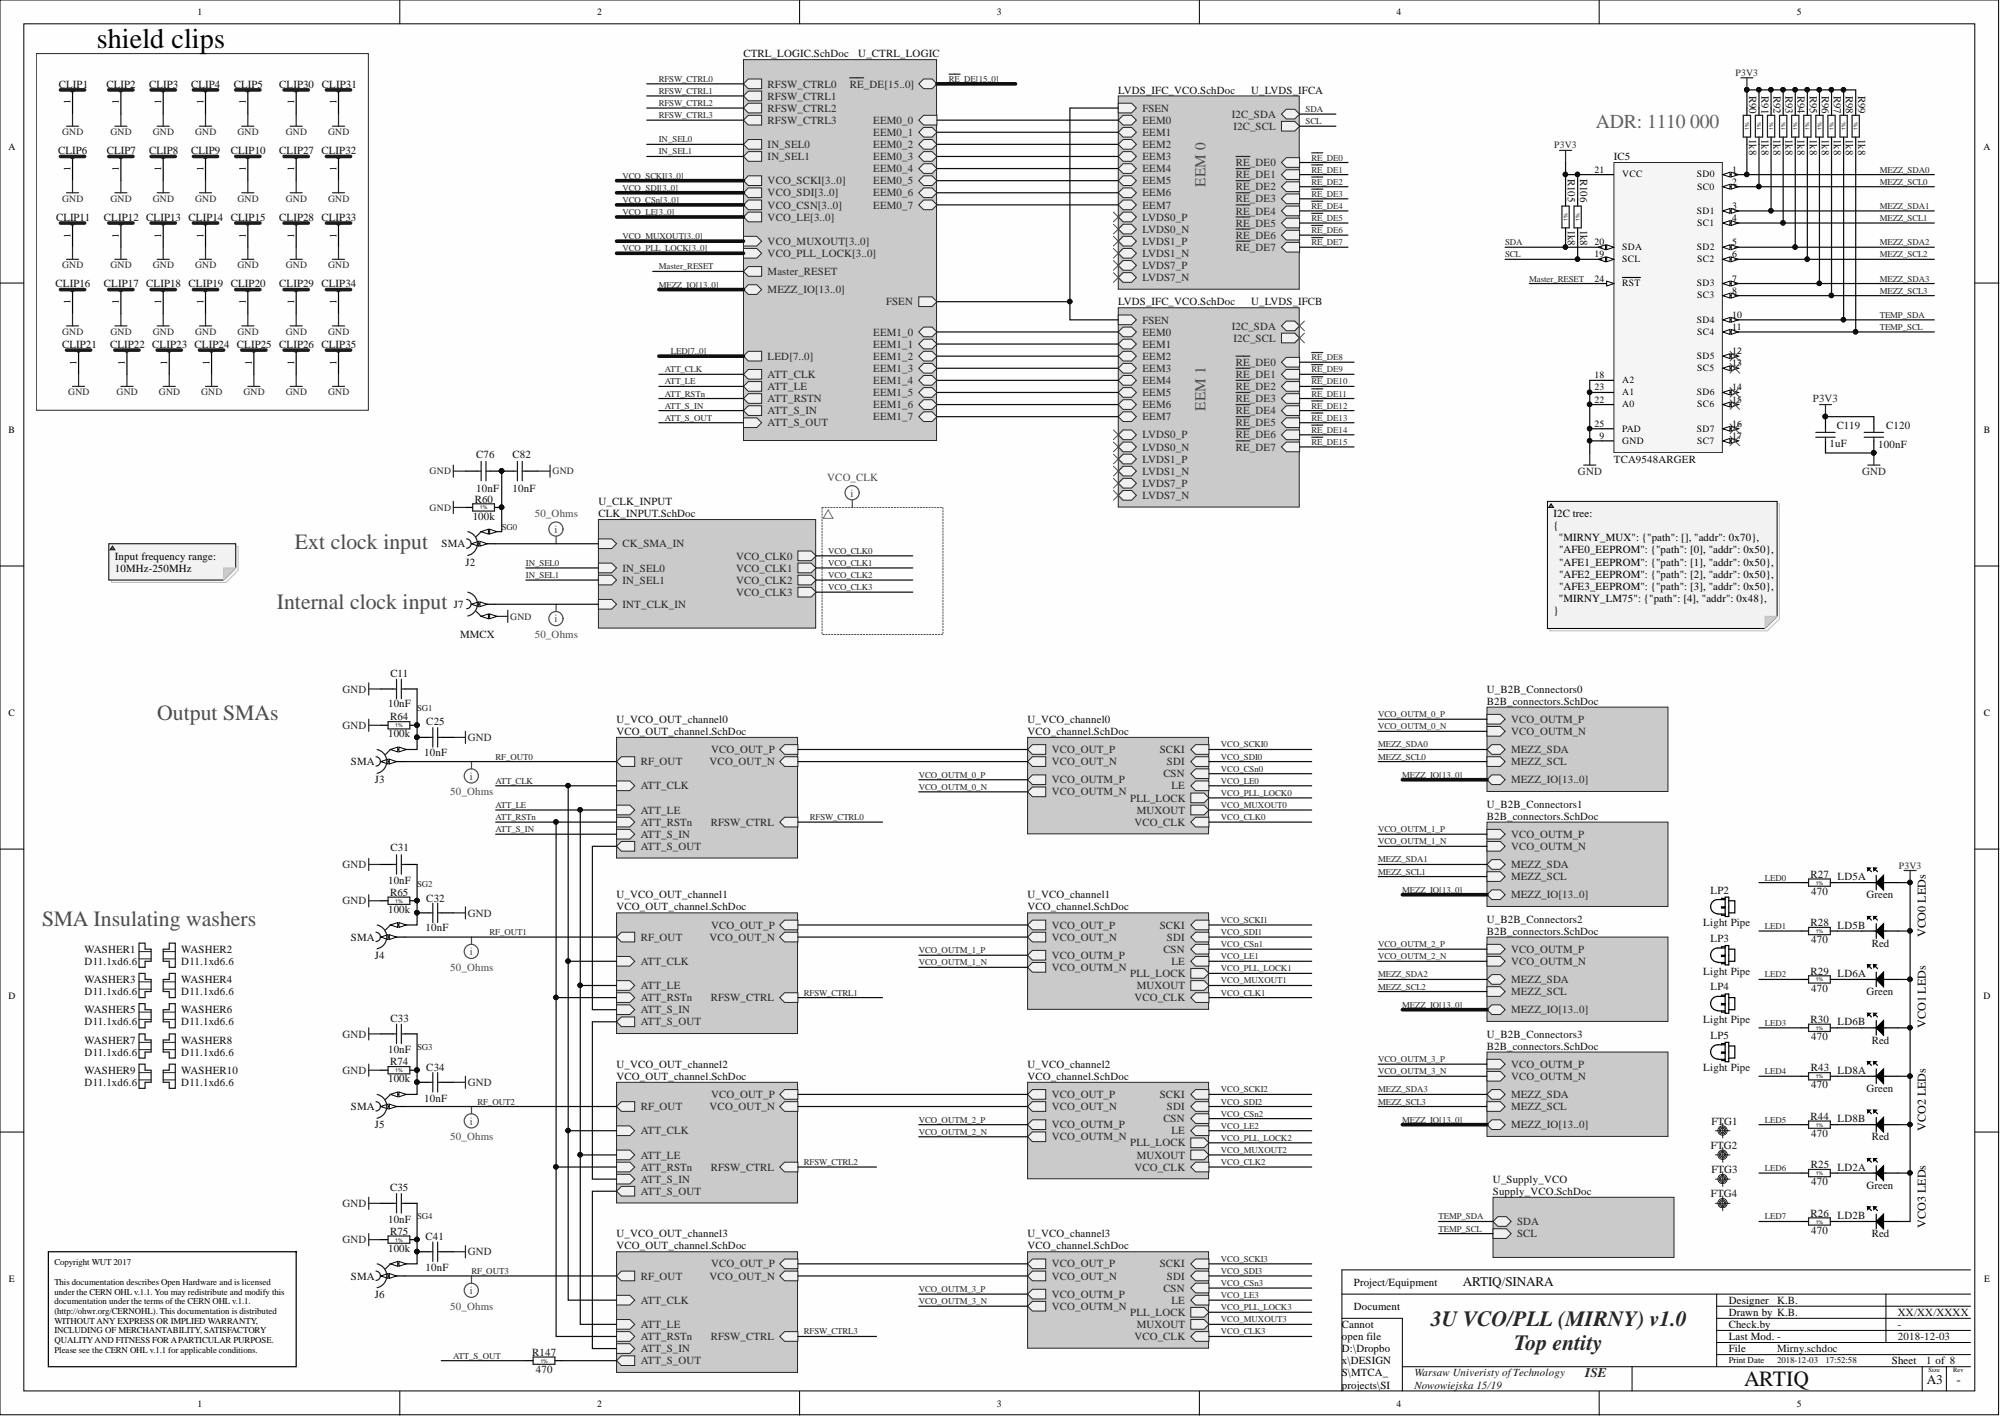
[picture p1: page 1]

VCO3 LEDs VCO0 LEDs VCO1 LEDs VCO2 LEDs

This documentation is distributed

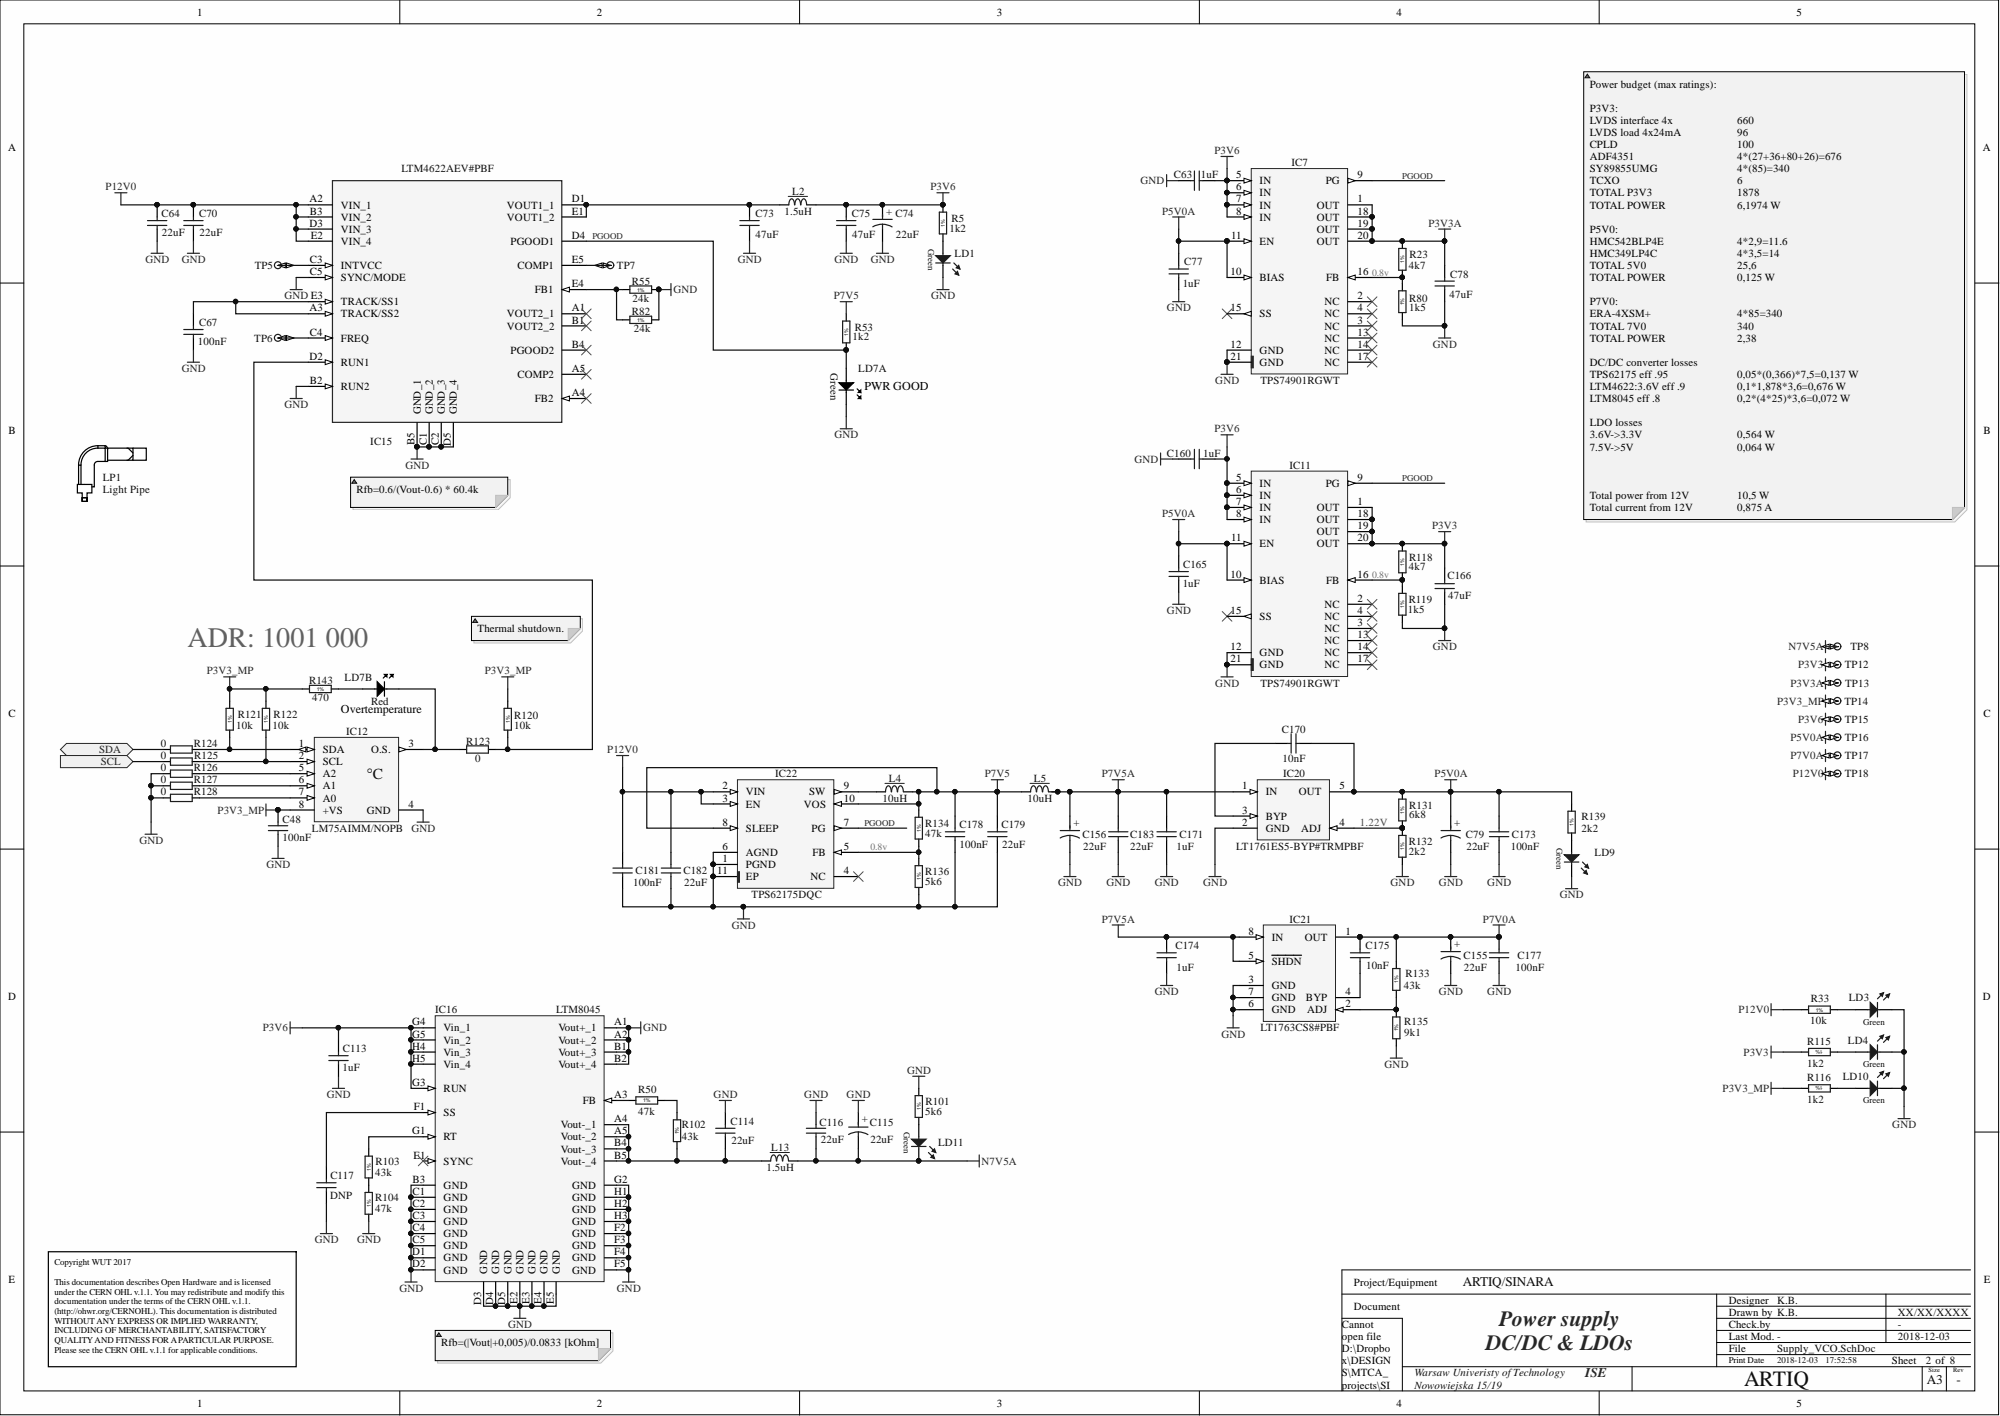
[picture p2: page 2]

Power budget (max ratings):

DC/DC converter losses

FB | 5 AGND 6

TPS62175DQC

This documentation describes Open Hardware and is licensed
under the CERN OHL v.1.1. You may redistribute and modify this
documentation under the terms of the CERN OHL v.1.1.
(http://ohwr.org/CERNOHL). This documentation is distributed
WITHOUT ANY EXPRESS OR IMPLIED WARRANTY,
INCLUDING OF MERCHANTABILITY, SATISFACTORY
QUALITYAND FITNESS FOR APARTICULAR PURPOSE.
Please see the CERN OHL v.1.1 for applicable conditions.

Warsaw Univeristy of Technology
Nowowiejska 15/19

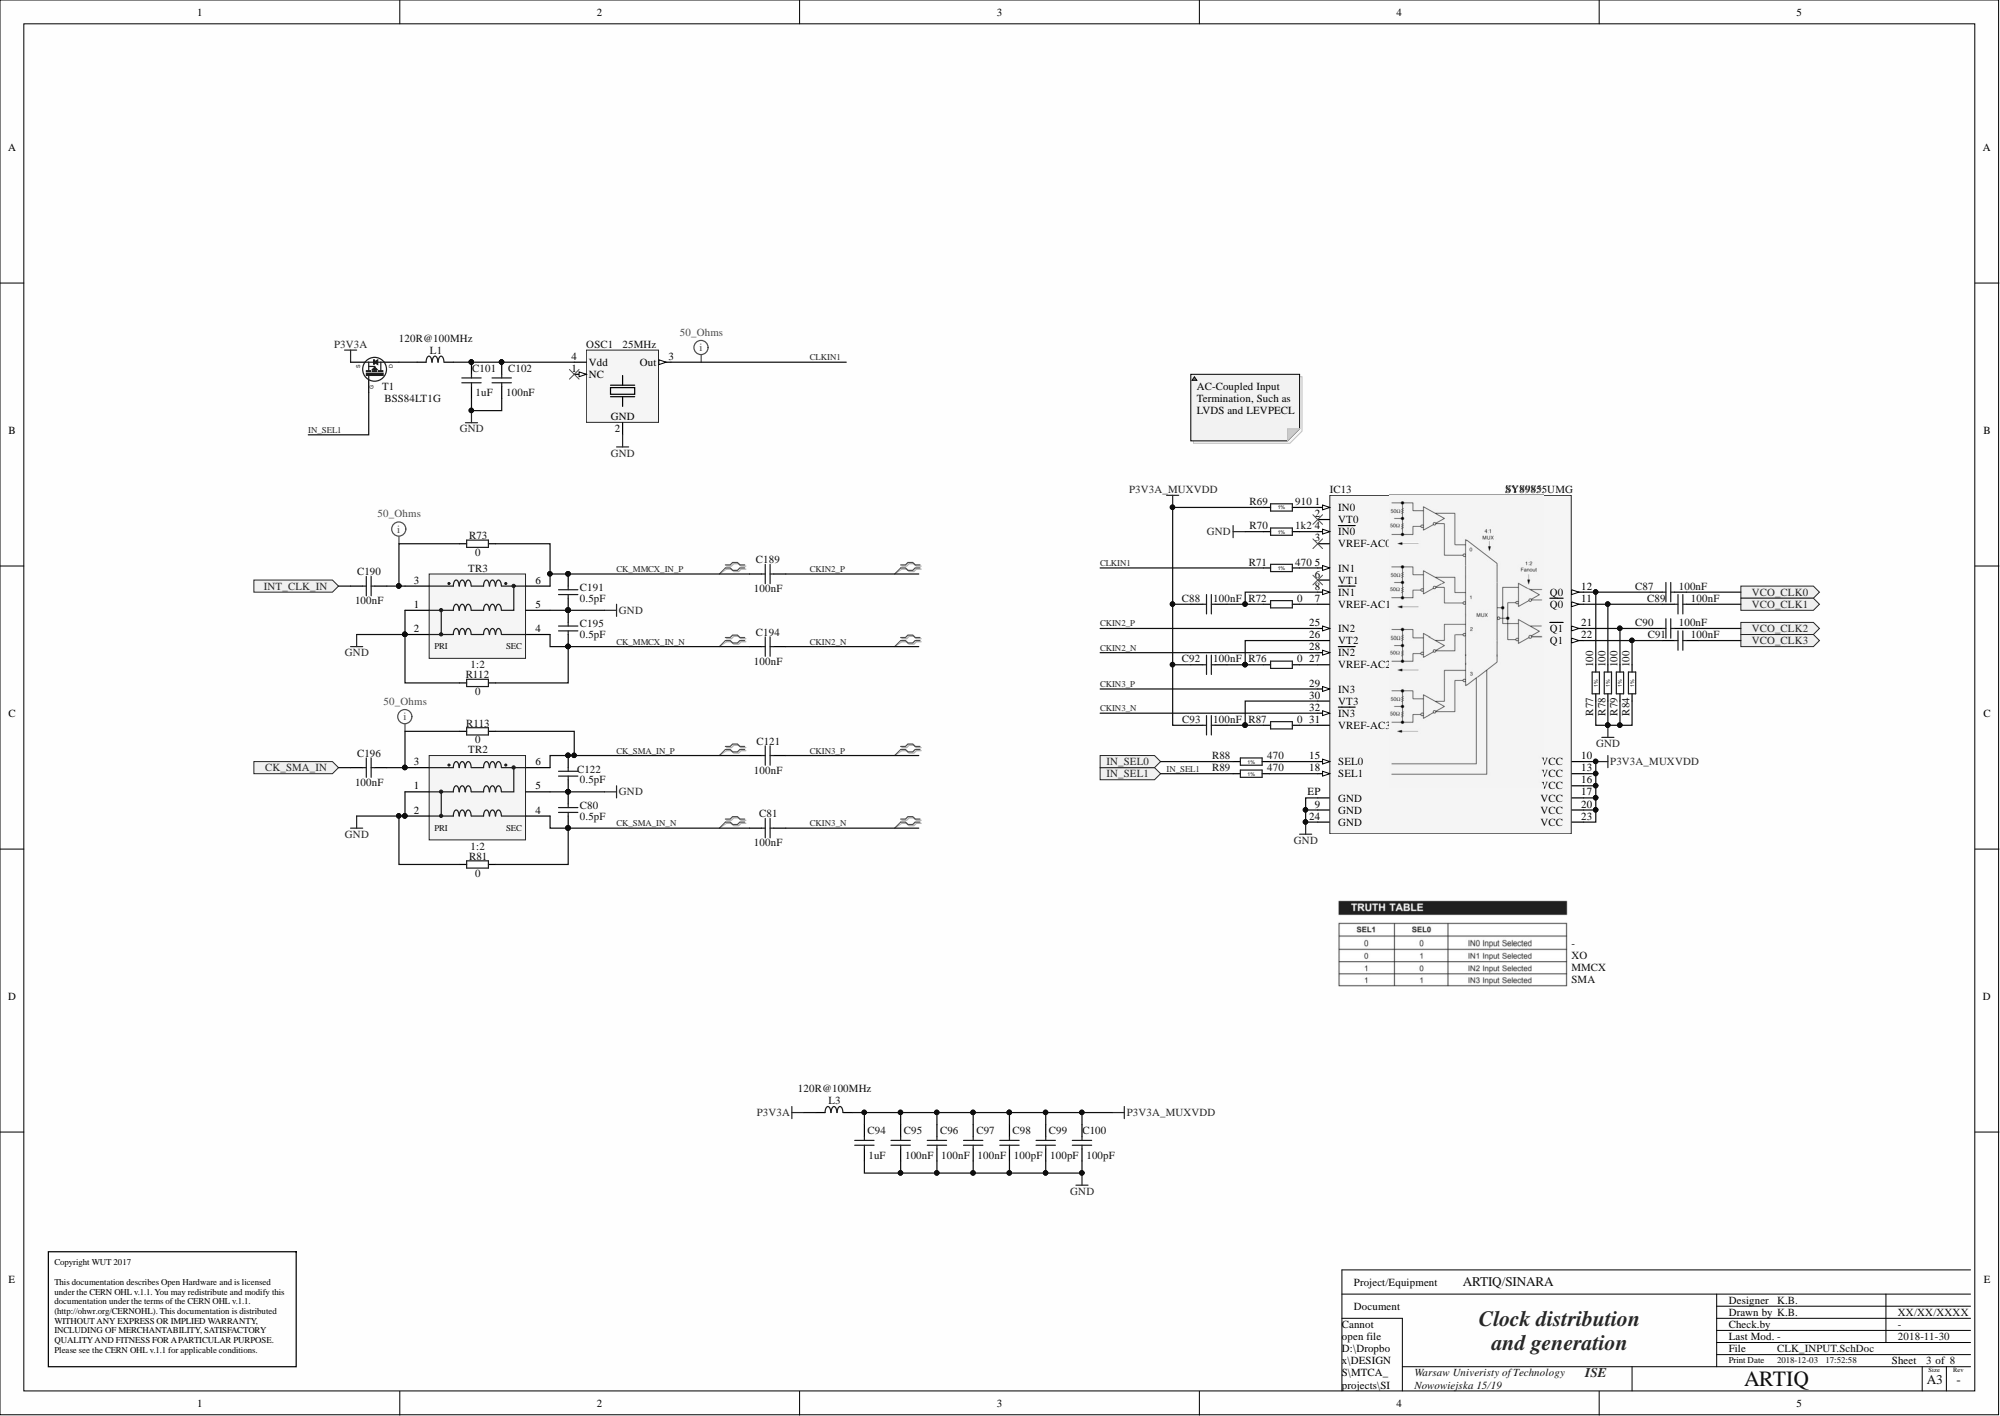
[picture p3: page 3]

VREF-AC2 27 IN2 28

VREF-AC3 31 IN3 32

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

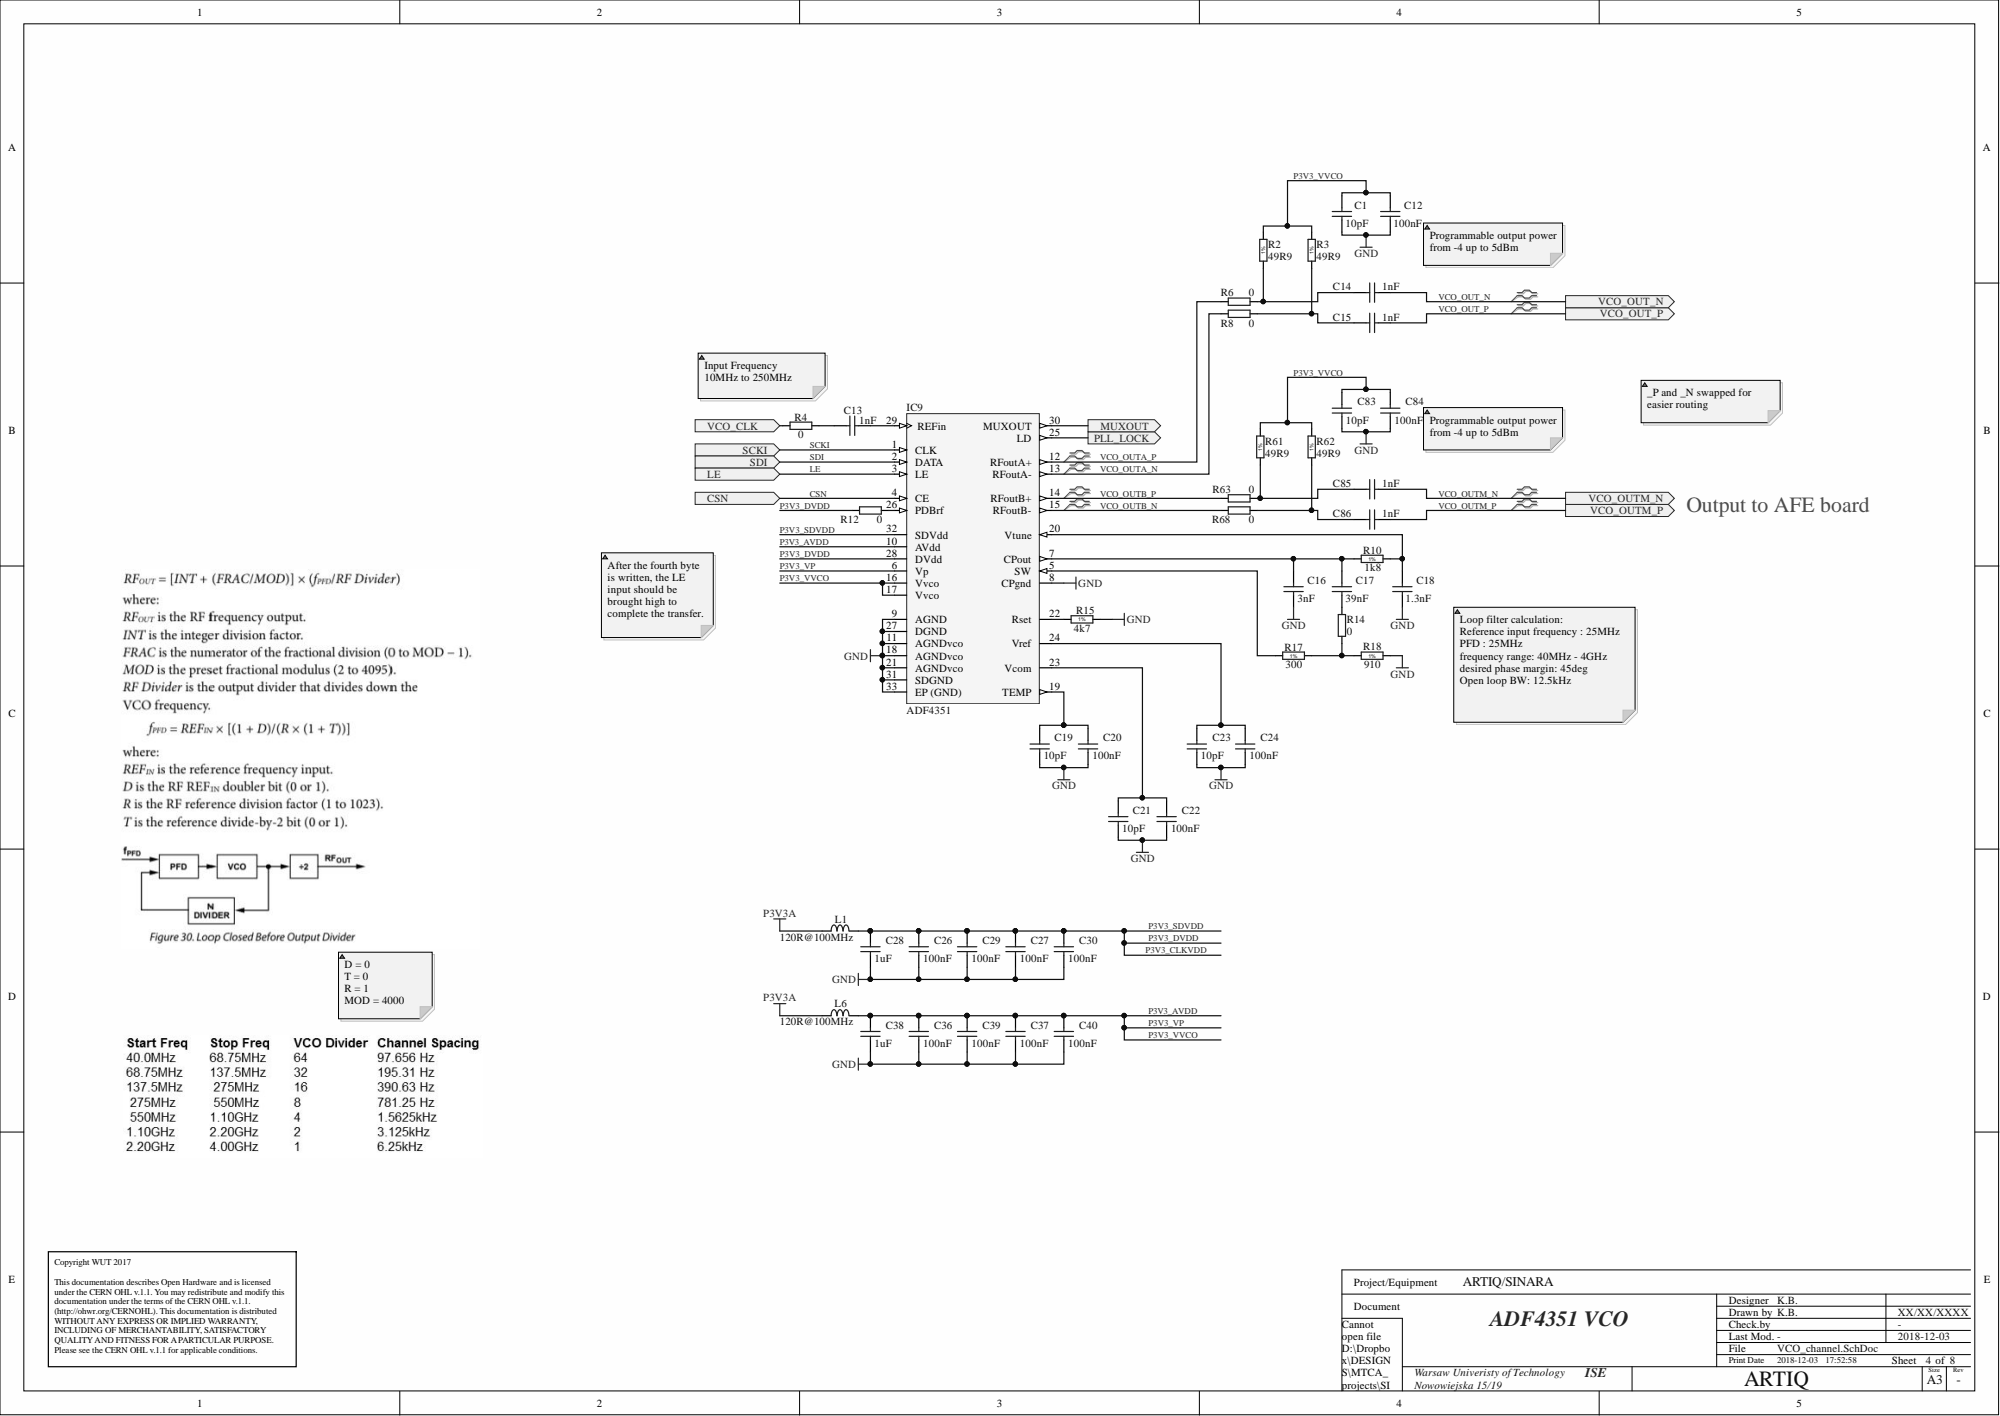
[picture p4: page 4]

Output to AFE board

After the fourth byte
is written, the LE
input should be
brought high to
complete the transfer.

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

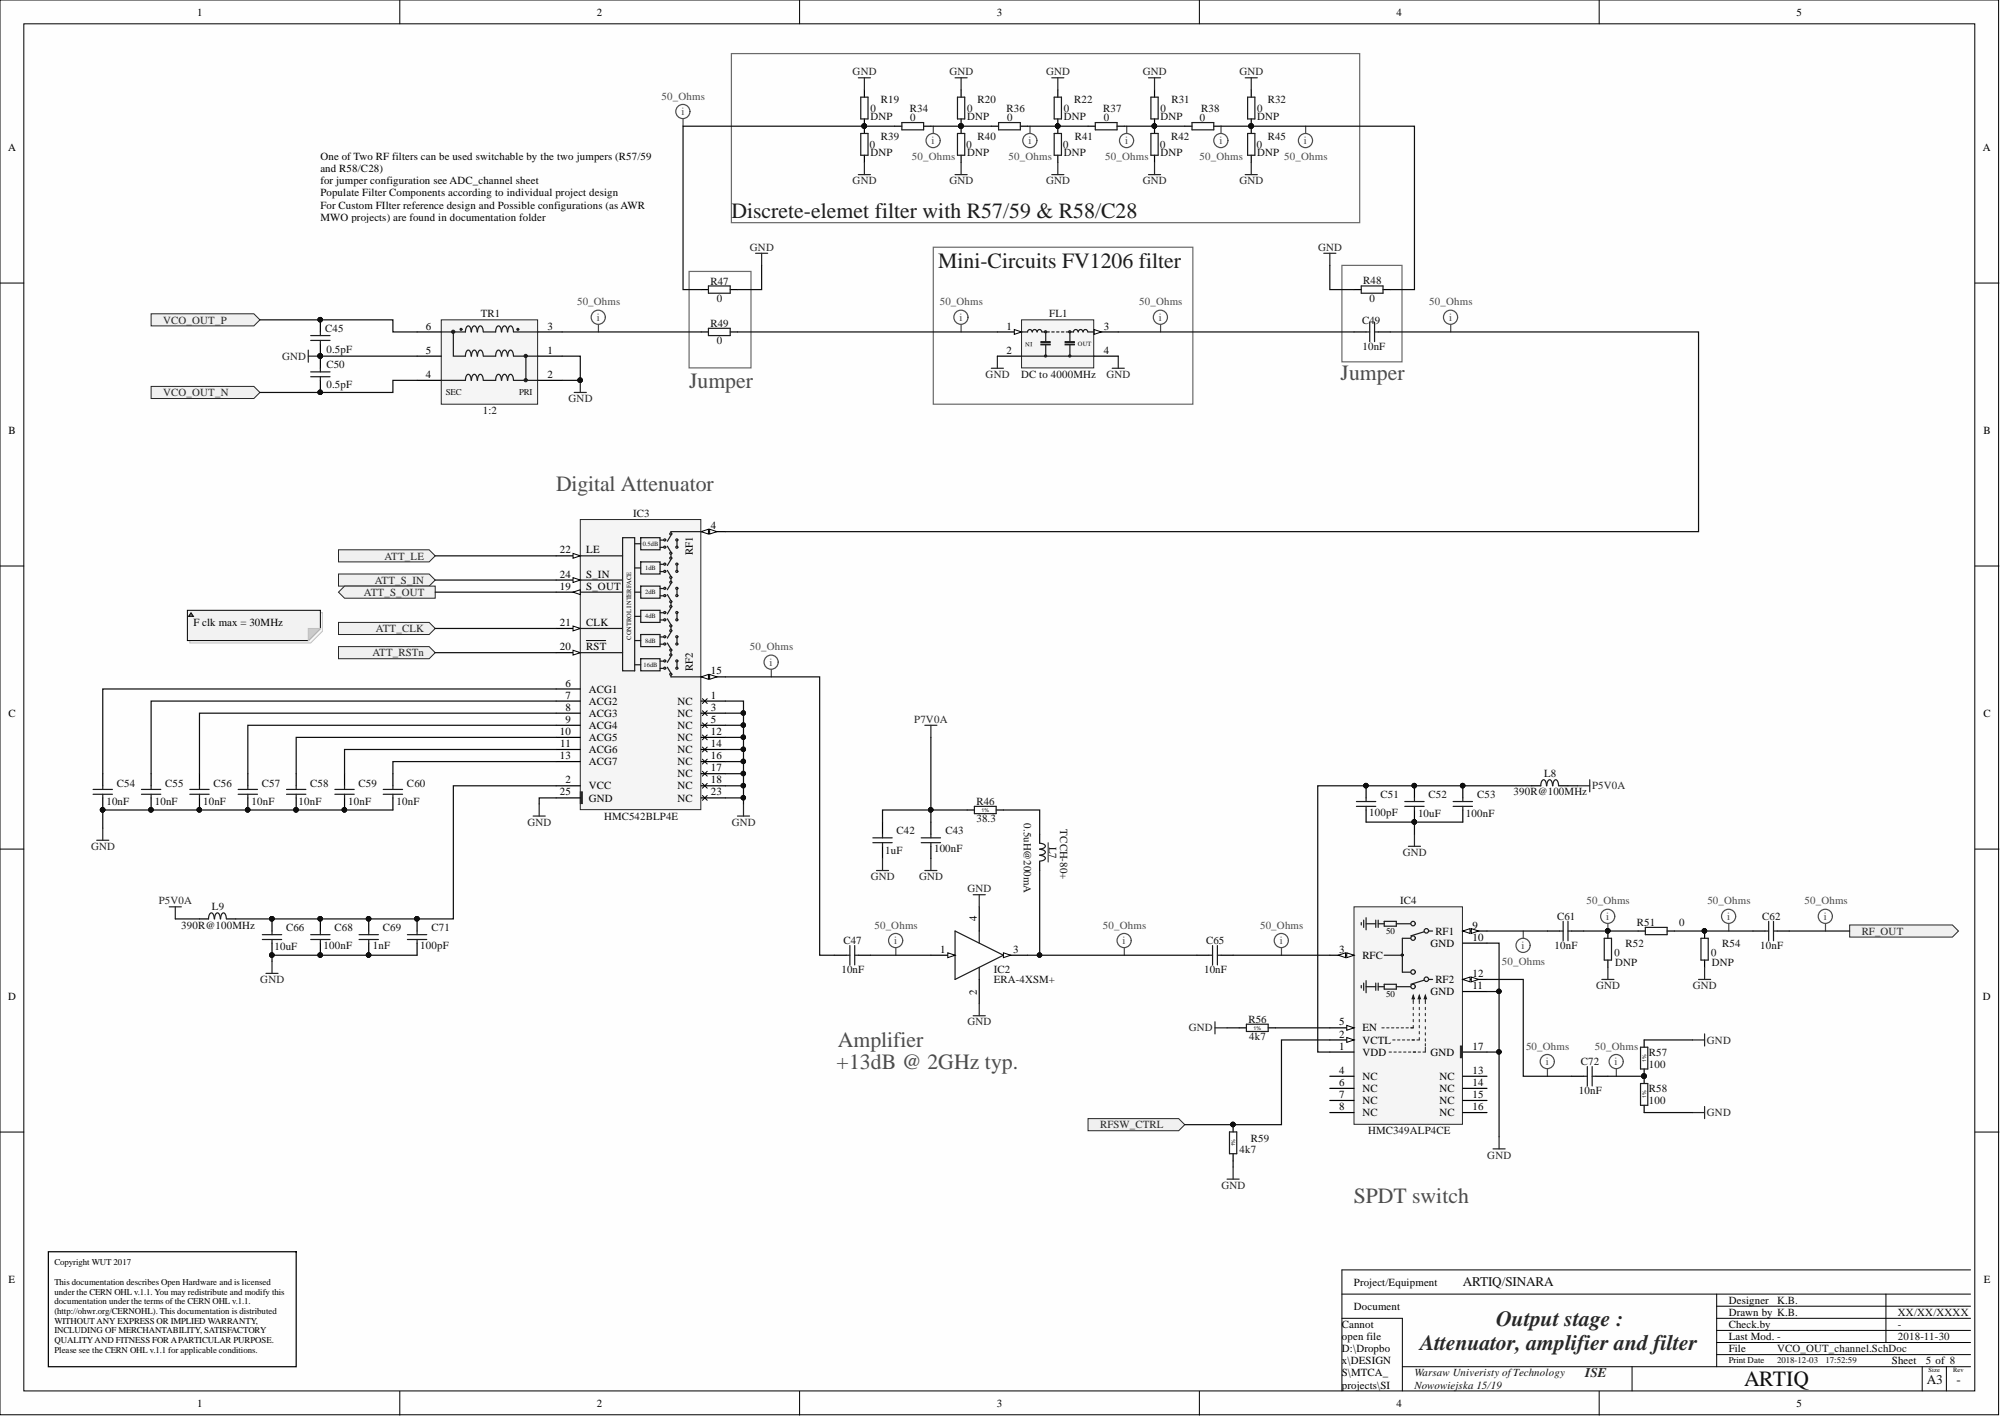
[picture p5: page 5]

One of Two RF filters can be used switchable by the two jumpers (R57/59
and R58/C28)
for jumper configuration see ADC_channel sheet
Populate Filter Components according to individual project design
For Custom FIlter reference design and Possible configurations (as AWR
MWO projects) are found in documentation folder

Discrete-elemet filter with R57/59 & R58/C28

1% | VCTL 2

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

Attenuator, amplifier and filter

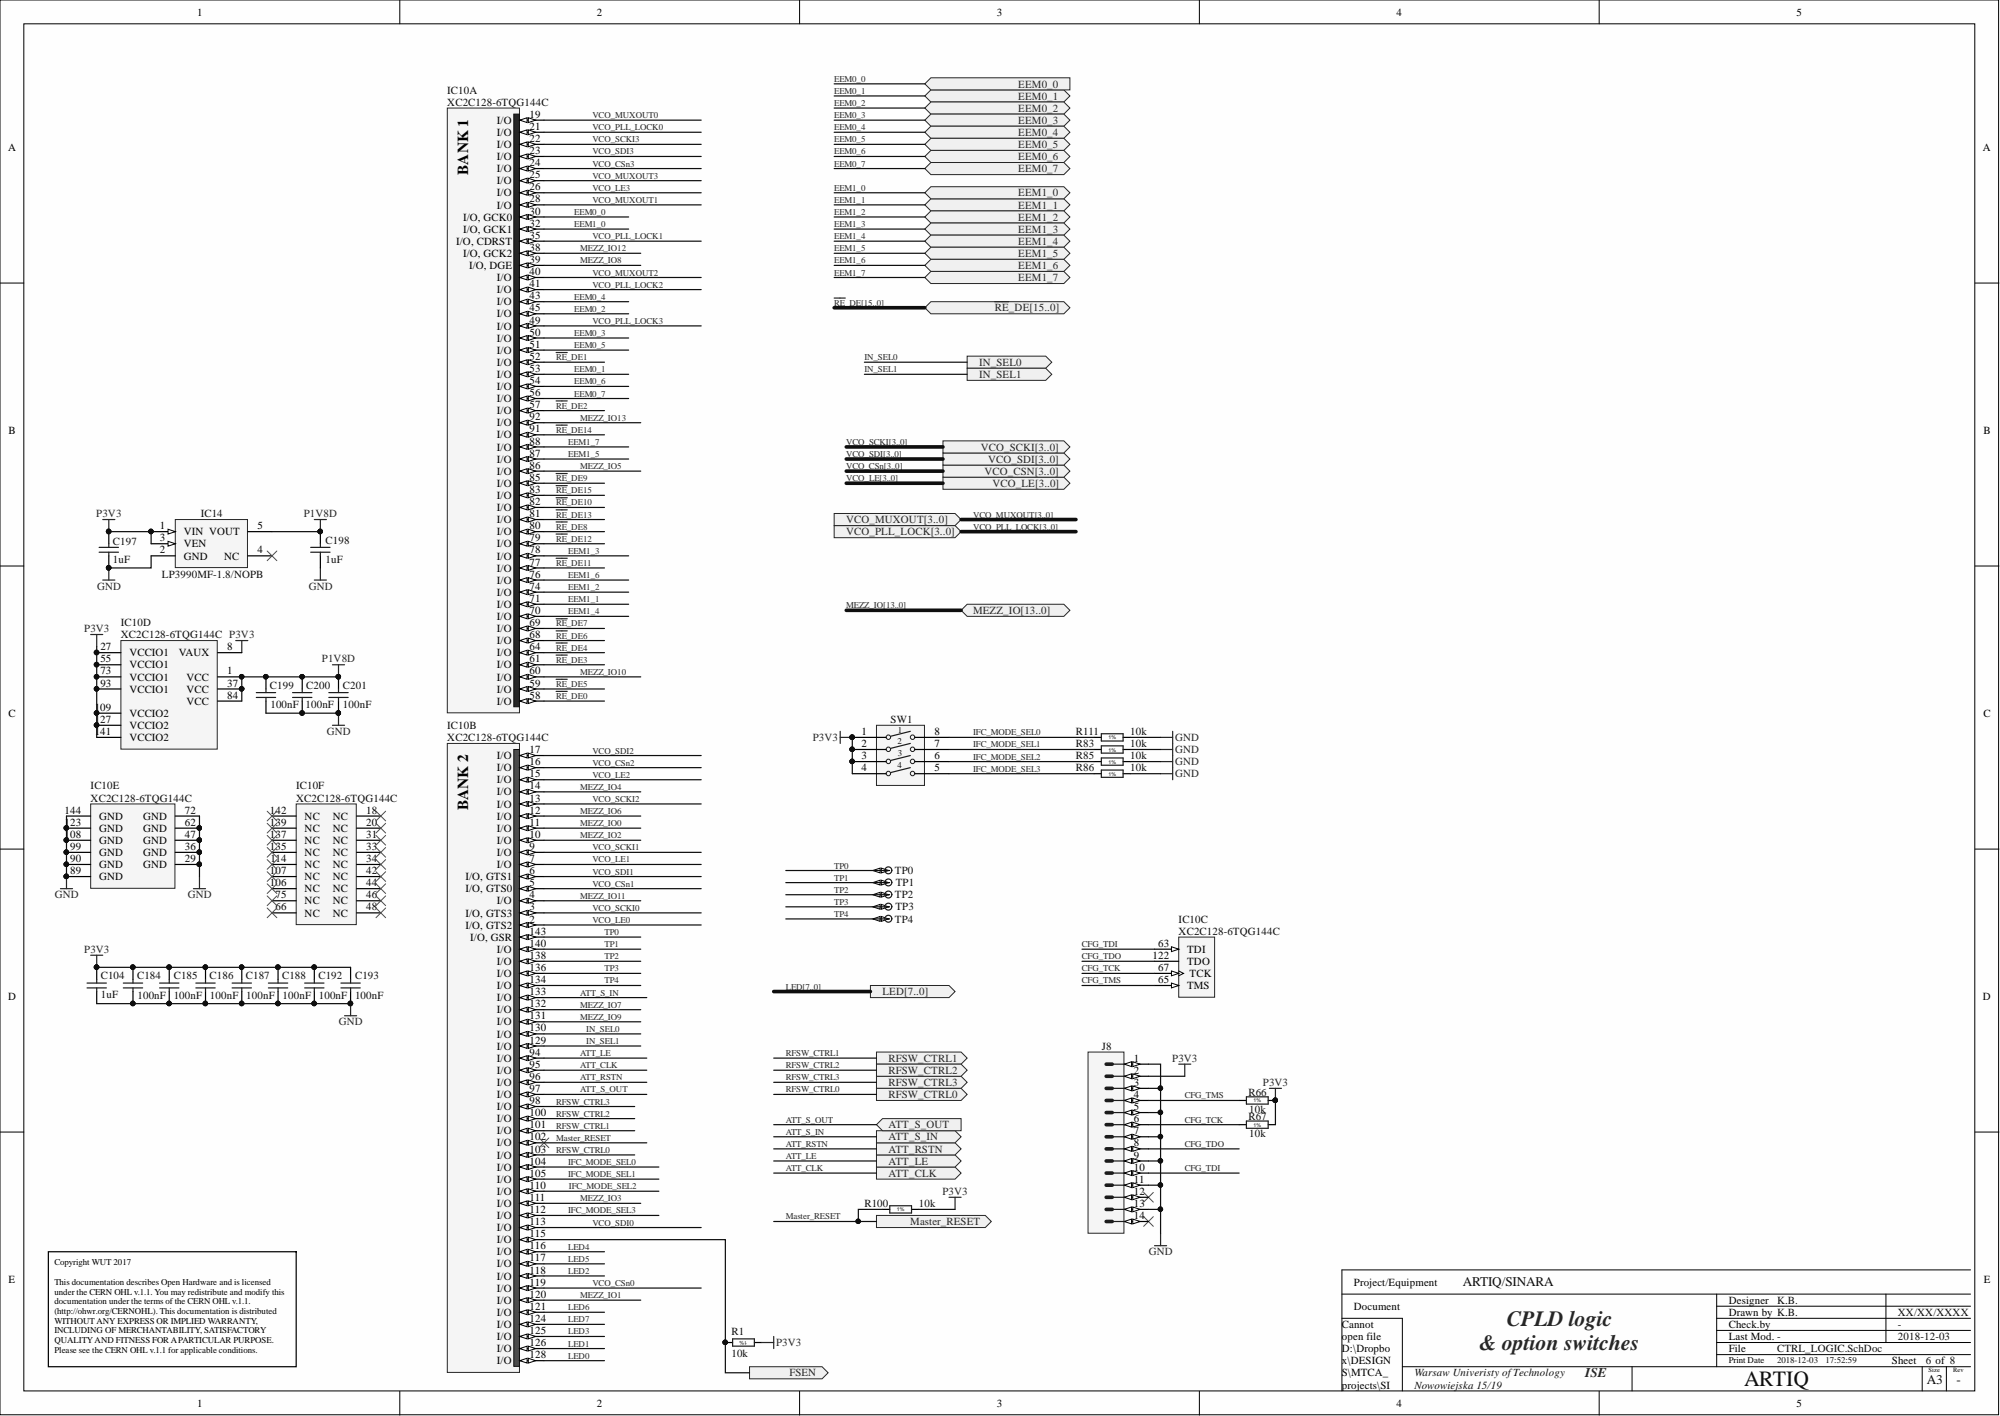
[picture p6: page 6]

9 3 | 3 7 | 9 | C2
1 0 9 | 8 4

1 2 3 | 6 2
1 0 8 | 4 7
9 9 | 3 6
9 0 | 2 9

This documentation is distributed

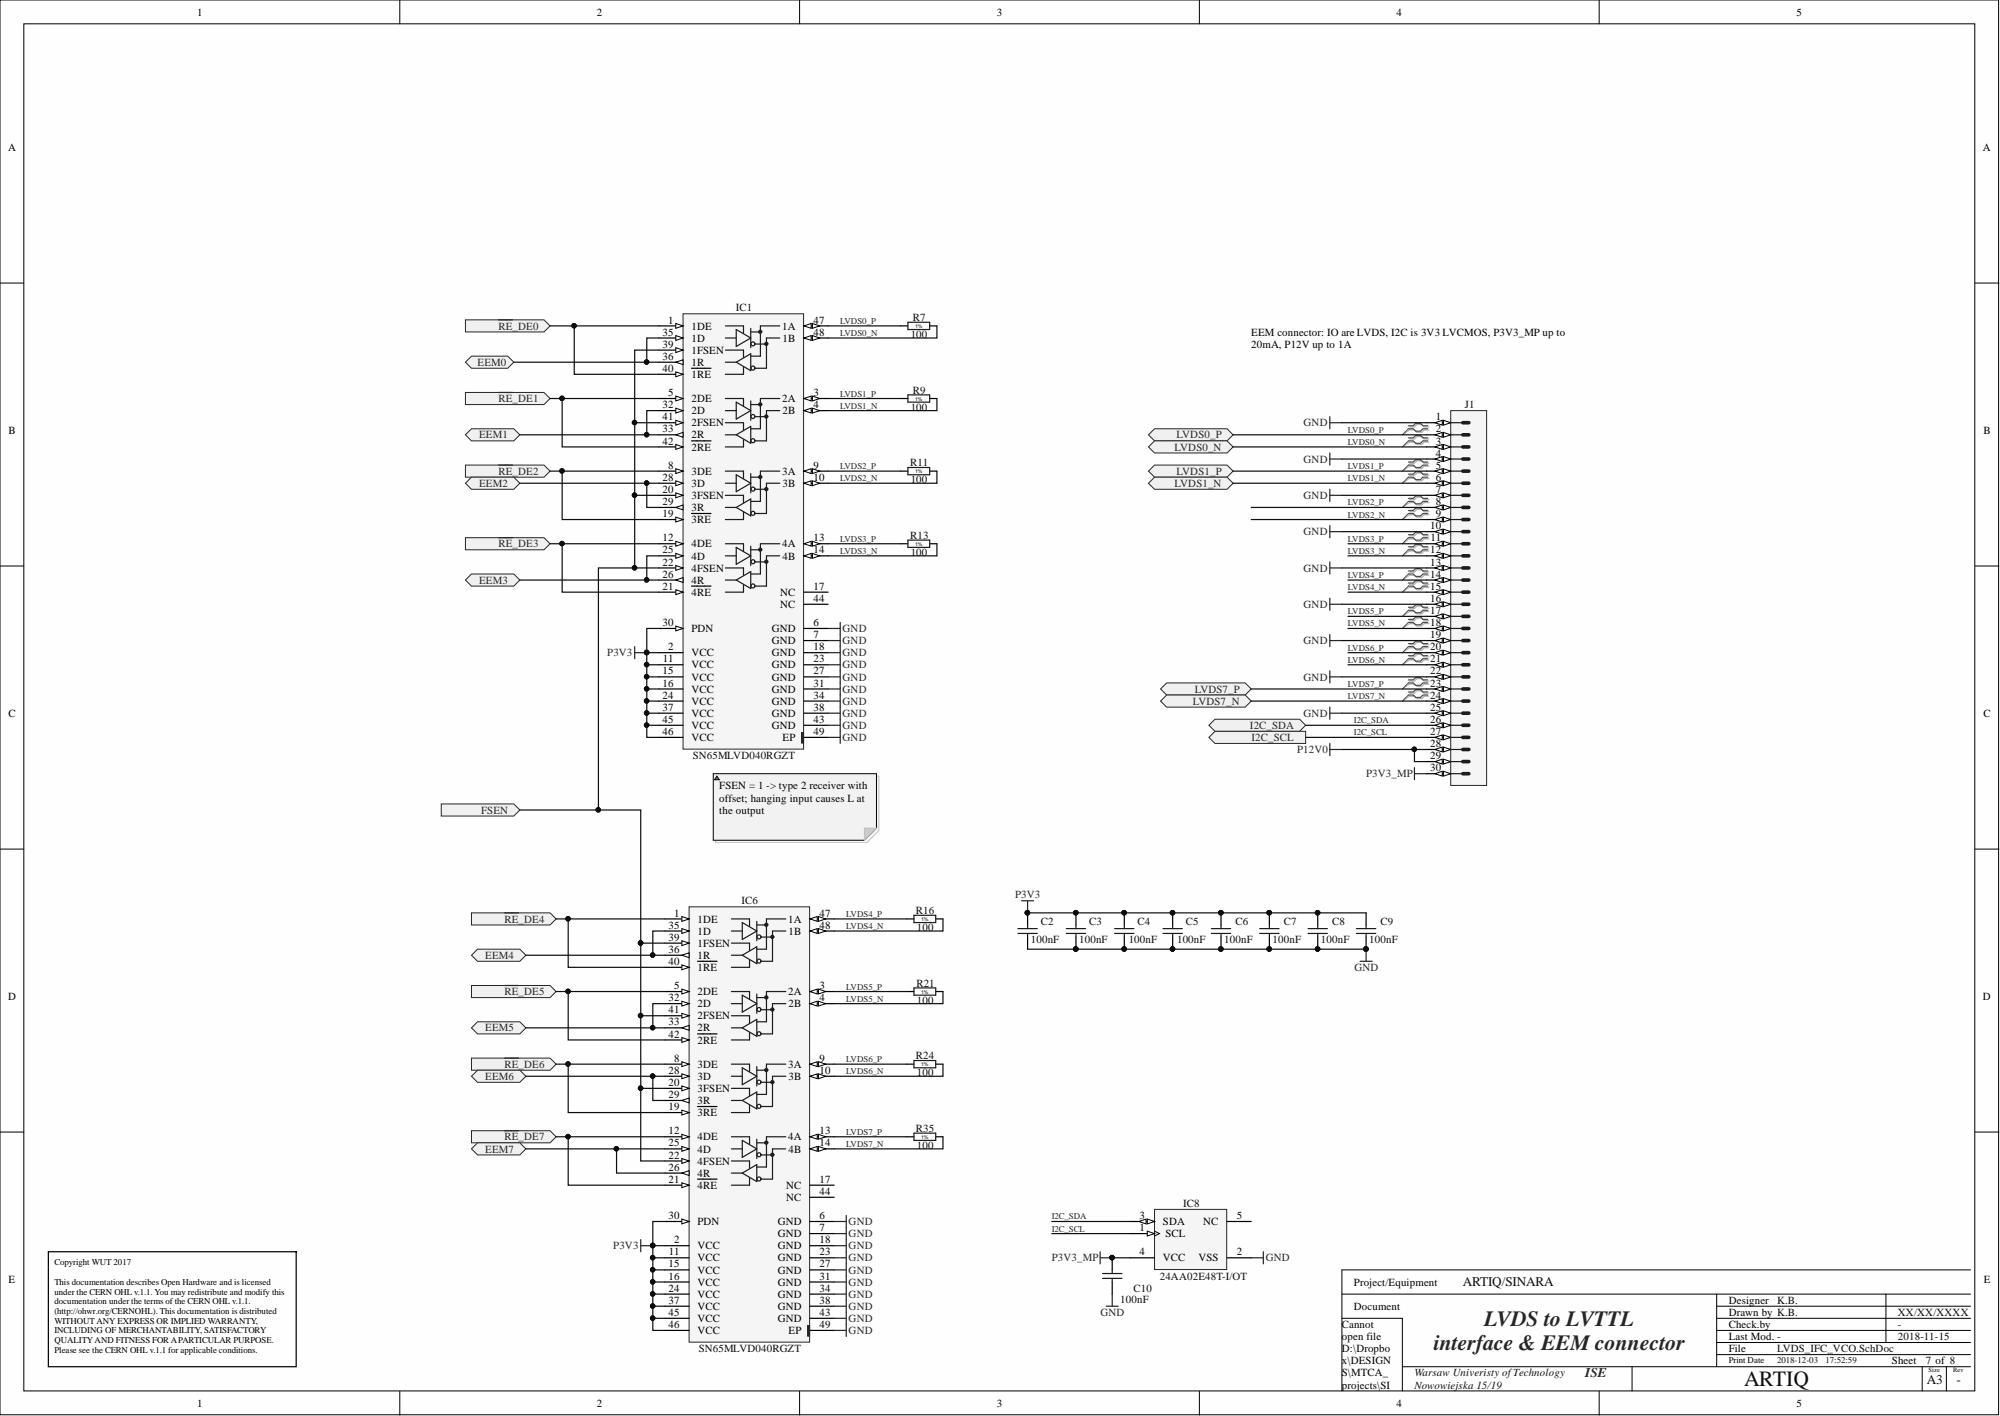
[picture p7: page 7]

EEM connector: IO are LVDS, I2C is 3V3 LVCMOS, P3V3_MP up to

LVDS1_N | 1% 100

2D 32
2FSEN 41
2R 33 2RE 42

3D 28 3FSEN 20

LVDS2_N | 1% 100

LVDS3_N | 1% 100

4FSEN 22
4R 26 4RE 21

PDN 30

FSEN = 1 -> type 2 receiver with
offset; hanging input causes L at
the output

LVDS4_N | 1%

1FSEN 39
1R 36 1RE 40

LVDS5_N 100

1% LVDS6_N 100

LVDS7_N | 1% 100

4D 25 4FSEN 22

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

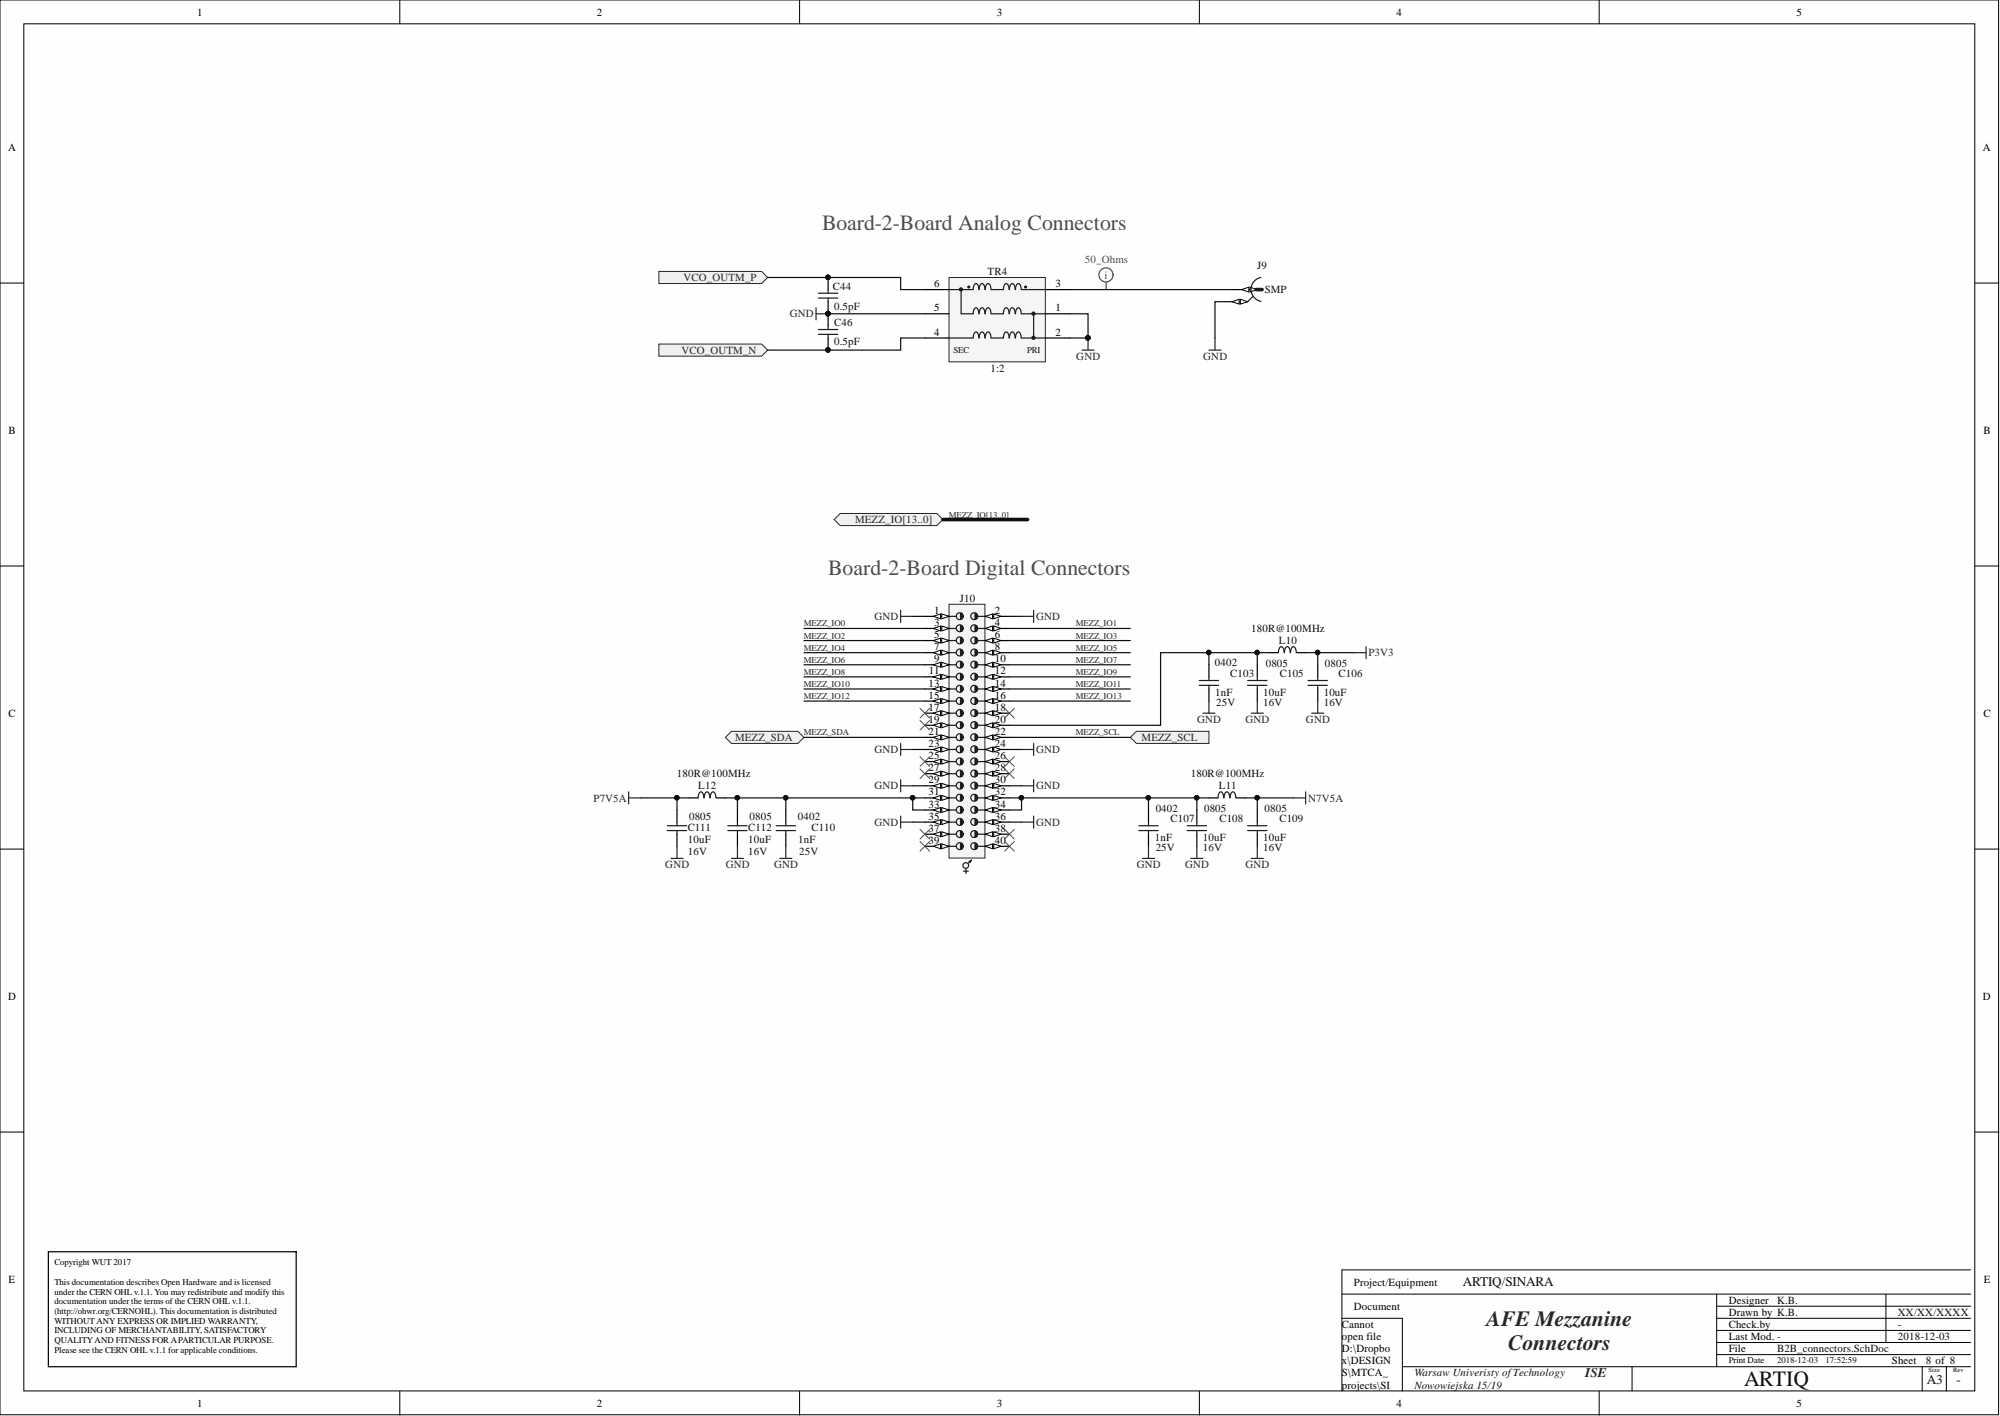
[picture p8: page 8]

Board-2-Board Analog Connectors

0.5pF | | SEC PRI

Board-2-Board Digital Connectors

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

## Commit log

2018-07-25 initial version of schematics
    - EEM connector to be removed
    - frequency multipliers missing
    [CTRL_LOGIC.SchDoc, LVDS_IFC_VCO.SchDoc, Mirny.PrjPCB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]
2018-10-15 Added clock input mux, AFE connectors, bypassed filter by default
    [B2B_connectors.SchDoc, CLK_INPUT.SchDoc, CTRL_LOGIC.SchDoc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]
2018-11-15 Added AFE Mezzanine template
    [B2B_connectors.SchDoc, Mirny_AFE_Template.PcbDoc, Mirny_AFE_Template.PrjPCB]
2018-11-15 Added Mezzanine I2C mux
    [B2B_connectors.SchDoc, CLK_INPUT.SchDoc, CTRL_LOGIC.SchDoc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]
2018-11-15 Added front panel
    [Panel_Mirny.PcbDoc, Panel_Mirny.PrjPCB, Panel_Mirny.step]
2018-11-15 Added lightpipes
    [Panel_Mirny.PcbDoc, Panel_Mirny.step]
2018-11-15 Fixed annotation
    [B2B_connectors.SchDoc, CTRL_LOGIC.SchDoc]
2018-12-02 Initial routing
    [B2B_connectors.SchDoc, CLK_INPUT.SchDoc, CTRL_LOGIC.SchDoc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]
2018-12-03 Added I2C tree, fixed LED resistors
    [B2B_connectors.SchDoc, CTRL_LOGIC.SchDoc, Mirny.schdoc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]
2018-12-06 2nd EEM removed, renderings and stackup added to PDF, I2C address fixed, FL1 bypassed
    [B2B_connectors.SchDoc, CLK_INPUT.SchDoc, CTRL_LOGIC.SchDoc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]
2018-12-16 IC19 changed to ADF4355, Input mux changed to Si53312, 12V rail added to AFE connector
    [B2B_connectors.SchDoc, CLK_INPUT.SchDoc, CTRL_LOGIC.SchDoc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]
2019-01-15 Updated IC9 cap values, added HW rev resistors
    [B2B_connectors.SchDoc, CLK_INPUT.SchDoc, CTRL_LOGIC.SchDoc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]
2019-01-22 Matched lengths of EEM0[4..7], added note on schematics
    [Mirny.PrjPCB, Mirny.schdoc, Supply_VCO.SchDoc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]
2019-01-28 EEM_0 swapped to clock capable pin
    [CTRL_LOGIC.SchDoc]
2019-01-28 I2C switch removed
    [Mirny.PrjPCB, Mirny.schdoc]
2019-01-28 Outjob update
    [Mirny.PrjPCB]
2019-01-29 C170, C175 changed to 100pF, Balancing pour added, fiducials/mounting holes/ testpoints excluded from BOM
    [Mirny.PrjPCB, Mirny.schdoc, Supply_VCO.SchDoc]
2023-11-03 v1.1.2 rc1
    [CLK_INPUT.SchDoc, LVDS_IFC_VCO.SchDoc, Mirny.PrjPCB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]
2023-11-03 v1.1.2 rc2
    [Mirny.PrjPCB, Mirny.schdoc, Panel_Mirny.PcbDoc]
2023-12-12 - P_version parameter added - Schematic sheets numeration updated/ revision updated - Variants: undefined elements removed, fiducial targets added - SMA to DELOCK changed and moved - FP LED moved - D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
    [B2B_connectors.SchDoc, CLK_INPUT.SchDoc, CTRL_LOGIC.SchDoc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]
2023-12-12 v1.1.3rc1 - P_version parameter added - Schematic sheets numeration updated/ revision updated - Variants: undefined elements removed, fiducial targets added - SMA to DELOCK changed and moved - FP LED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
2024-02-01 v1.1.4 - Impedance profiles added - Stackup slightly adjusted - 50R traces slightly adjusted
    [Mirny.PrjPCB]
